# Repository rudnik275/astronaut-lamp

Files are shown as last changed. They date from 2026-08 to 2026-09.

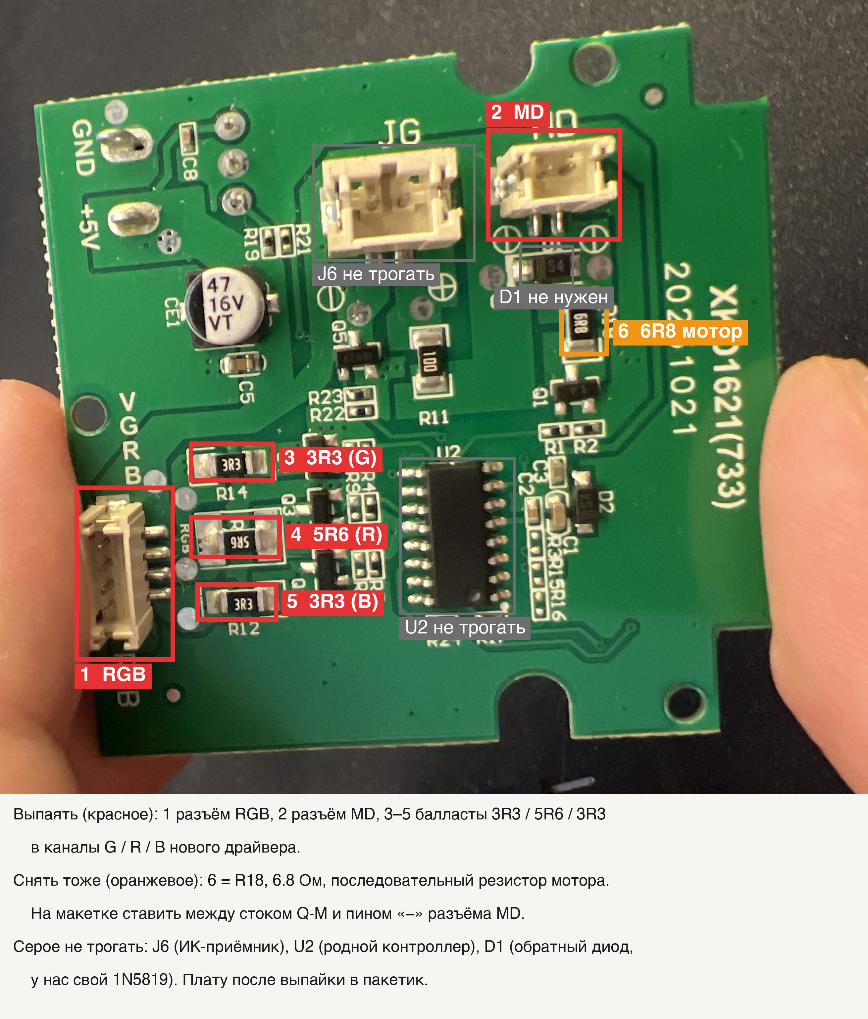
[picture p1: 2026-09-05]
photos/board-XKD1621-desolder.jpg

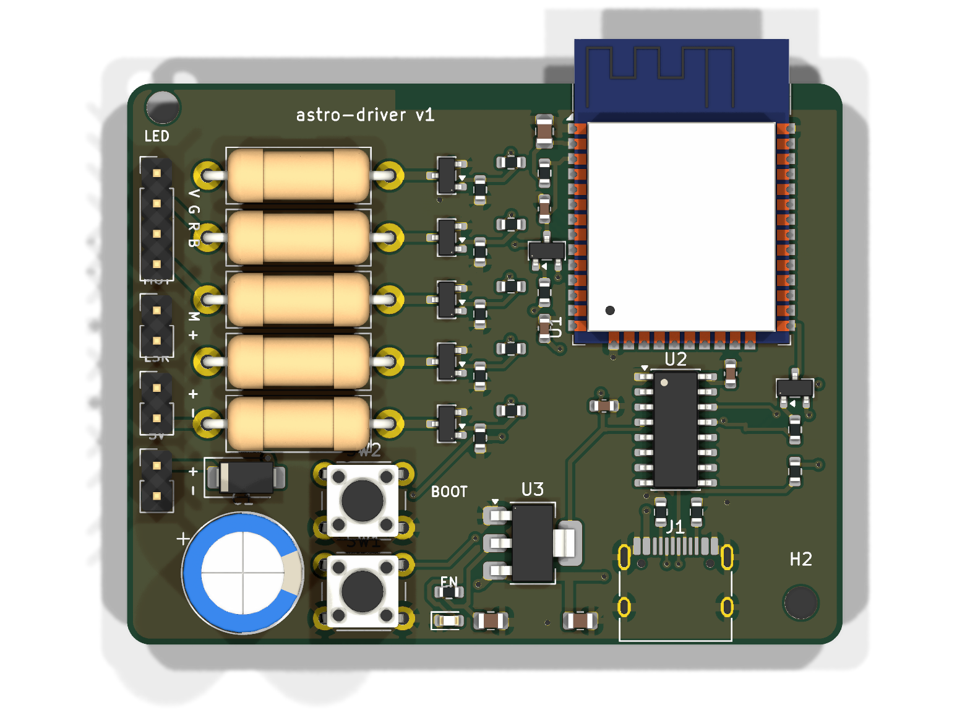
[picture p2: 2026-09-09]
hardware/out/render-top.png

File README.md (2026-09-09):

# Лампа-космонавт → нативное устройство Apple HomeKit

Ночник «космонавт на луне» + звёздный проектор (Rozetka 566431028, AURA_HUB, ~530 грн).
Куплен и разобран 2026-08-23. **Решение: выкидываем ИК-пульт и родной контроллер,
внутрь ставим ESP32-WROOM-32 с прошивкой HAA — лампа появляется в Apple Home как
настоящая цветная LED-лампа + отдельный выключатель проектора, без хабов и мостов.**

## Статус на 2026-09-05 (точка входа для новой сессии)

- ✅ **ESP32 прошит HAA 12.18.1 (04.09)** и **спарен с Home.app**. Чип ESP32-D0WD-V3,
  порт `/dev/cu.usbserial-120`, точка доступа setup-режима `HAA-620DA0`, код спаривания
  `0218-2017`. Имена в Home.app: аксессуар «Космонавт», лампа «Цвет неба», мотор
  «Движение неба». Уровни на GPIO проверены мультиметром: 25 = R, 26 = G, 27 = B, 32 = мотор
- ✅ **С донора выпаяны и промерены** балласты `5R6` (R) и 2× `3R3` (G, B) **плюс `6R8` (R18)**
  из цепи мотора — на доноре мотор шёл `MD → D1 → 6R8 → Q1`, а не напрямую (§1, §3).
  Гнёзда `RGB`/`MD` оказались SMD с шагом 2.0 мм: вилки с кабелей срезаны, кабели теперь
  с голыми концами, провода светодиода опознать по фото вилок
- 📐 **Схема, таблица соединений для breadboard, порядок работ и раскладка в корпус:**
  `docs/schematic.html` (та же страница опубликована как артефакт, ссылка в памяти сессии).
  Конфиг HAA, залитый в плату: `docs/haa-config.json`. Размеченное фото донора:
  `photos/board-XKD1621-desolder.jpg`
- 🔧 **Монтаж на перфборде (08.09):** `docs/wiring.html` — карта 14 проводов (пин ESP32 →
  отверстие), раскладка по отверстиям платы 10 × 24 (вид сверху и зеркальный вид снизу),
  правила пайки на перфборде, порядок сборки, чеклист. Раскладка: TO-220 плашмя, ноги в ряд H,
  резисторы стоя в рядах I–J, шина GND голым проводом по ряду G снизу, шина +5 по ряду I
  в колонках 21–24, C1 на боку в колонках 21–24, D1 в `I20–I21`. 10 кОм стоит со стороны GPIO
  от 220 Ом (эквивалентно схеме). Плата берётся целиком, 25.4 × 61 мм после обрезки полей —
  отсек ранца считать под неё, а не под 24 × 58. Связи раскладки проверяются скриптом на
  самой странице (18 цепей, замыканий и разрывов нет)
- 🖨️ **Печатная плата astro-driver v1 (09.09):** `hardware/` — проект KiCad 10 с ESP32-WROOM-32E
  на плате, USB-C (питание + прошивка через CH340C), пять ключей AO3400A (R, G, B, мотор,
  лазер на GPIO 33), выводные балласты 2 Вт и 1000 µF под ручную пайку. 60 × 47 мм.
  Схема и плата генерируются из `hardware/design.py` (`sh hardware/run.sh all`), нетлист
  схемы сверен с платой, DRC без электрических ошибок, 0 неразведённых. Гербер, BOM/CPL
  для сборки на JLCPCB, рендер и PDF схемы в `hardware/out/`. Цена: голые платы ~15–22 $
  за 5 шт, со сборкой SMD ~40–50 $ за 2 шт / ~55–70 $ за 5 шт (оценка, `hardware/README.md`).
  **На железе не проверено**, первая партия — прототип. Лазер в текущей ручной сборке
  висит параллельно мотору; на плате у него свой канал
- 🧩 **Корпус: печатаем новый ранец.** Отсек 63 × 52 × 20 мм, ESP32 со срезанной гребёнкой
  плашмя + полоска перфборда 24 × 58 рядом, один слой (раскладка в `docs/schematic.html`).
  Вход питания — **USB-C** вместо круглого: в корзине Али два кандидата с 5.1 кОм — на фланце
  (item 1005006939718172) и платка без фланца Choice (item 1005012148102188); 2-pin без CC
  и XH2.54 не брать (§4)
- ✅ **Драйвер спаян и работает (08.09):** перфборд по схеме §3 (своя раскладка), лампа
  и мотор управляются из Home.app. Лазер звёзд (разъём `JG` донора, §1) в параллель мотору
  через `R11` 10 Ом. **Решение 09.09: железо закрыто в таком виде**, пятый ключ, пересборка
  и печатная плата не делаются
- ⏭️ **Следующий и последний шаг:** конфиг HAA с эффектами (`"fx"`, плитки-выключатели
  эффектов), залить по Wi-Fi через режим настройки — [issue #3](https://github.com/rudnik275/astronaut-lamp/issues/3)
- 📄 Инвентарь деталей: Obsidian `справочники/электроника-инвентарь.md`; где покупать —
  `справочники/электроника-где-покупать.md` (там же USB-C гнёзда по трём магазинам)
- 🧭 Дальше по плану работ — §6

Связанные проекты: [nodemcu-co2](../nodemcu-co2/) (общий пул плат), Fusion/3D-печать
(держатель платы внутри основания — печатает друг, Bambu A1, PETG).

---

## 1. Что внутри (по фото разобранного основания)

Родная плата: **`XKD1621(733)`**, дата-код `231021`. Питание 5 В (пады `+5V` / `GND`
внизу справа), электролит 47 µF 16 V.

| Разъём / метка | Пины | Что это |
|---|---|---|
| `RGB` | 4: `V G R B` | **Аналоговый RGB-светодиод, общий анод** (`V` = +5 В). Ключи `Q2/Q3/Q4` (SOT-23) стоят по низкой стороне на R/G/B, рядом балласты `3R3`. |
| `MD` | 2 | Мотор звёздного проектора (`MD` = motor drive). Цепь по чистому фото (05.09): `MD → D1` (Шоттки `S4`) `→ R18 = 6R8 → Q1`. **Не Q5**, как думали по первому фото: `Q5` с `R11` (10 Ом) стоит у `J6`. |
| `JG` | 2 | **Лазер звёзд** (`JG` = 激光 jīguāng, лазер; раньше по фото ошибочно считали ИК-приёмником `J6`). Его драйвер: ключ `Q5` (SOT-23) + `R11` = `100` (10 Ом) последовательно + электролит `CE1` 47 µF. Уточнено 08.09.2026, когда после сборки не оказалось звёзд. Лазер полярный, в отличие от мотора. |
| `U2` | SOIC-16 | Родной контроллер: декодирует пульт, гонит ШИМ на Q2–Q4. Его и выбрасываем. |

**Ключевой вывод:** здесь **НЕ адресная лента (не WS2812B)**, а обычный RGB с общим
анодом на трёх ШИМ-каналах. Значит не нужны ни level shifter 3.3→5 В, ни DMA-пины,
ни ограничения WLED по GPIO. Задача сводится к «три ШИМ-канала + один ключ мотора».

Сам номер платы `XKD1621(733)` — это внутренний код китайского ODM-цеха, даташита нет
нигде и не будет (искали EN+ZH — ноль). Опознаём снизу вверх по функциям, и это не
проблема: схема этого класса ламп стандартна и совпала с референс-дизайнами
(Cmsemicon SC8F052 и подобные) пин-в-пин — «RGB-выходы active-low, общий анод, три
NPN/ключа по низкой стороне, 3-проводной ИК-приёмник». То есть наши догадки по фото
подтверждаются типовым дизайном.

### Что переиспользуем с платы, а что выкидываем

Ключевая мысль: **RGB-светодиод и мотор сидят на съёмных разъёмах** (белые JST на фото).
Их можно просто **отстегнуть от родной платы и воткнуть в свой драйвер на ноде** —
резать провода не обязательно.

| С платы | Решение |
|---|---|
| **RGB-светодиод** (разъём `RGB`, `V G R B`) | **Переиспользуем.** Это и есть свет лампы. `V` = общий +5 В анод. |
| **Мотор проектора** (разъём `MD`) | **Переиспользуем.** Отдельный ключ = отдельный сервис в Home. |
| **Питание 5 В** (родной адаптер → пады `+5V`/`GND`) | **Переиспользуем**, если адаптер тянет (проверить ток, см. §5). |
| Корпус, крепления, JST-разъёмы | **Переиспользуем.** |
| **U2** (16-pin) — родной мозг/ИК-декодер | **Выкидываем**, его роль берёт NodeMCU. |
| **J6** (3 пина) — ИК-приёмник | **Не нужен**, управление по Wi-Fi. |
| Q2/Q3/Q4 (ключи RGB), Q5 (ключ мотора) | **Опционально** — см. две стратегии ниже. |

**Стратегия A — свой драйвер (выбрана и реализована).** Родную плату не трогаем
вообще: отстёгиваем разъёмы `RGB` и `MD`, ведём их в свой маленький драйвер на 4
logic-level MOSFET (схема в §3). *Поправка 04.09: гнёзда на плате оказались SMD с шагом
2.0 мм, dupont в вилки не входит, поэтому вилки с кабелей срезаны и кабели идут в драйвер
голыми концами. С платы сняты только четыре резистора: `5R6`, 2× `3R3`, `6R8`.* Плюс: полностью известная схема, никакой пайки SOIC.
Минус: докупить 4 транзистора (копейки).

**Стратегия B — переиспользовать родные ключи (экономит детали).** Выпаять U2 и
подать ШИМ с ноды прямо на входы Q2/Q3/Q4/Q5 (через их же базовые/затворные резисторы).
Плюс: 0 новых деталей. Минусы: надо выпаять 16-ногую SOIC (лучше феном) и прозвонить,
какая нога куда шла; работает чисто, **если** ключи — это NPN-биполярники (для 5-В лампы
очень вероятно, референс использует S8050) или logic-level MOSFET. Если это MOSFET с
высоким порогом — от 3.3 В не откроются, тогда всё равно Стратегия A.

**Как выбрать за 2 минуты мультиметром:** посмотреть на вход Q2. Резистор ~1 кОм в
управляющую ногу = биполярник (Стратегия B безопасна). Голый затвор + подтяжка вниз =
MOSFET (проверить порог). Не хочешь возиться — бери Стратегию A.

**Стратегия C — ИК-инъекция (идея Димы): плату не трогаем вообще, выбрасываем ИК-приёмник
и подаём сигнал с ESP прямо на его пин.** Разобрана отдельно в §2.5. Электрически чисто и
это самый быстрый путь, но платой управляет по-прежнему родной U2, а он понимает только
язык пульта — поэтому в Home.app получится не лампа, а набор кнопок. Подробности и
цифры — там же.

### Сравнение трёх стратегий

| | Что делаем | Цвет в Home.app | Яркость | Состояние | Цена |
|---|---|---|---|---|---|
| **A. Свой драйвер** | 4 MOSFET на макетке, ESP рулит светодиодом напрямую | **любой, цветовой круг** | **плавно 0–100 %** | **точное** | 4 транзистора + час пайки |
| **B. Убить U2** | выпаять SOIC-16, ШИМ с ESP на базы родных ключей | **любой, цветовой круг** | **плавно 0–100 %** | **точное** | фен + прозвонка, 0 покупок |
| **C. ИК-инъекция** | один провод в разъём `J6`, ESP притворяется пультом | только **16 пресетов** | только ступеньками `±` | **вслепую** | один провод |

**Рекомендация: A** (или B, если любишь паять и не хочешь ничего покупать). Стратегия C
даёт «умную лампу» в кавычках — ровно то, от чего отказались в самом начале, просто
без ИК-светодиода.

---

## 2. Архитектура (выбрана)

**NodeMCU V3 (ESP8266) + прошивка HAA (Home Accessory Architect, RavenSystem).**

HAA — единственная живая прошивка с **нативным HomeKit на ESP8266** (последний релиз
v12.18.1 «Merlin», 2026-07-26). Лампа регистрируется в Home.app **как настоящий
HomeKit-аксессуар: без Home Assistant, без Homebridge, без NAS и без моста**.
Поддерживает ровно нашу схему: Lightbulb с ШИМ-каналами `"g":[R,G,B]`, плюс вторым
сервисом Switch на мотор проектора.

⚠️ **Бинарники лежат в репозитории `RavenSystem/haa`, а не в `esp-homekit-devices`** —
у второго в релизах вообще нет файлов, только changelog. Проверено 2026-08-23: в релизе
12.18.1 лежит 80 ассетов, ESP8266-сборки — это файлы **без суффикса** `_esp32*`
(`fullhaaboot.bin`, `haamain.bin`, `otamain.bin`). Сборки живые, не остатки: размер
`haamain.bin` меняется от релиза к релизу, и заголовок `fullhaaboot.bin` — настоящий
ESP8266-образ (magic `0xE9`, точка входа `0x401008dc` в IRAM ESP8266).

- Релизы (бинарники): https://github.com/RavenSystem/haa/releases
- Wiki Lightbulb: https://github.com/RavenSystem/esp-homekit-devices/wiki/Lightbulb
- Wiki GPIO: https://github.com/RavenSystem/esp-homekit-devices/wiki/GPIOs-Configuration
- Wiki установки: https://github.com/RavenSystem/esp-homekit-devices/wiki/Installation

### Честно про риски ESP8266 (перепроверка 2026-08-23)

Плана это не ломает, но знать надо:

- **ESP8266 у HAA в режиме «поддерживаем, но не развиваем».** Все новые фичи идут только
  под ESP32 (HTTPS, MQTT, хардварный ШИМ, ADC-режимы). Автор прямым текстом в issue #2407:
  Wi-Fi-драйвер закрытый, а **SDK под ESP8266 Espressif забросил** (последний
  ESP8266_RTOS_SDK v3.4 — апрель 2021), поэтому баги Wi-Fi-слоя он починить не может.
- **Сам чип ESP8266EX — NRND с ноября 2025** (не рекомендован для новых разработок).
- Был реальный регресс в 2026: на 12.16 часть ESP8266-устройств отваливалась (issue #2408),
  закрыт как невоспроизводимый после 12.17.
- **Вывод:** для этой лампы ESP8266 берём осознанно — плата уже есть, задача простая
  (3 ШИМ + бинарный выход). Если бы железо покупалось с нуля — брал бы ESP32-C6.

### Прошивка HAA: конкретика

> ⚠️ **Секция историческая — писалась под ESP8266, до смены платы.** Номера GPIO
> (5/4/14/12), режим ШИМ `7` и команды esptool с `-fs 1MB -fm dout` здесь НЕ для
> нашего ESP32. Актуальное: пины и конфиг — §3, команды прошивки ESP32 — §6.
> Общие вещи (массив `"io"` обязателен, `"es"`-группировка, initial value) верны для обеих плат.

**Мотор делаем БИНАРНЫМ выходом, а не ШИМ.** Это важно: софтверный ШИМ на ESP8266
ограничен **2000 Гц** (дефолт 305 Гц), и мотор на такой частоте будет слышимо пищать.
Нам скорость вращения регулировать не надо — только вкл/выкл, поэтому проблемы нет.
Если позже захочется «медленное вращение» — это аргумент за ESP32 (там хардварный ШИМ
до 29 кГц), на ESP8266 будет писк.

**Лимит, который надо помнить:** одна служба Lightbulb принимает **максимум 5 ШИМ-каналов**
(в исходниках `uint8_t gpio[5]`). Наши R/G/B — три, всё ок, но мотор четвёртым каналом
лампы сделать нельзя даже при желании — только отдельным сервисом. Мы так и планировали.

**ШИМ НЕ инвертируем.** Общий анод + N-ключ по низкой стороне = «единица на затворе»
означает «горит», это нормальный режим (`PWM mode 0` — дефолт). Но **осознанно задать
initial value**, иначе на старте лампа может вспыхнуть на полную до инициализации службы.

Скелет конфига (R/G/B на GPIO 5/4/14, мотор на GPIO 12). Обязателен массив `"io"` —
без него GPIO просто не включатся, это самая частая ошибка новичка:

```json
{
  "c": { "io": [ [[5,4,14], 7], [[12], 2] ] },
  "a": [ {
    "t": 30,
    "g": [5,4,14],
    "es": [ { "t": 1, "0": {"r":[[12,0]]}, "1": {"r":[[12,1]]} } ]
  } ]
}
```

`"c"` — общие настройки, `"a"` — массив аксессуаров, `"es"` — дополнительные службы
внутри аксессуара (так экономится RAM и всё группируется одной плиткой в Home.app).
Режим GPIO `7` = софтверный ШИМ-выход, `2` = бинарный выход. `"t":30` = Lightbulb,
`"t":1` = Switch. Точные ключи сверить по wiki перед заливкой.

**Команды прошивки** (плата 4 МБ, но образ собран под 1 МБ — флаг `-fs 1MB` правильный,
«помогать» флагом `4MB` не надо; GPIO0 на GND для входа в режим прошивки):

```
python3 -m esptool flash_id
python3 -m esptool erase_flash
python3 -m esptool -b 115200 --before=default_reset --after=hard_reset write_flash -fs 1MB -fm dout 0x0 fullhaaboot.bin
```

В Home.app будет предупреждение «непроверенный аксессуар» → **«Всё равно добавить»**.

В Home.app получится **один аксессуар с двумя сервисами**: «Космонавт» (цвет + яркость)
и «Звёздное небо» (вкл/выкл, при желании — скорость вращения через ШИМ).

### Почему не альтернативы

| Путь | Вердикт |
|---|---|
| **HAA (выбран)** | Нативный HAP, нулевая инфраструктура, PWM RGB из коробки. Минус: конфиг — JSON («MEPLHAA script»), не такой привычный как YAML; спаривание на ESP8266 небыстрое. |
| ESPHome + Home Assistant на NAS + HomeKit Bridge | Полноценный план Б, живее чем казалось: в релизе **ESPHome 2026.1 (январь 2026) поддержку ESP8266 официально переподтвердили** («ESP8266 is no longer a platform we warn users away from»), интеграция в HA — Platinum. Минус прежний: тянет всегда-включённый NAS и мост, нативного HomeKit у ESPHome нет. Плюс: HA крутит свои автоматизации вообще без Apple-хаба. В Docker нужен `network_mode: host` (иначе mDNS не пролезет). |
| WLED | Нативного HomeKit нет вообще, и он про адресные ленты — у нас их нет. Мимо. |
| HomeSpan | Только ESP32. NodeMCU V3 не подходит. |
| Оставить ИК и подменять пульт | Отменено пользователем — хотим настоящее устройство, а не эмуляцию кнопок. |
| **Aqara Hub M3** (встроенный ИК-бластер) | Не отменяет план — см. ниже. Даёт ту же «эмуляцию кнопок», от которой отказались, и лампой-с-цветовым-кругом она в Home.app не станет. |

### Про Aqara Hub (и любой хаб): ноду он в HomeKit НЕ заведёт — и не нужен

Путь «NodeMCU → Apple HomeKit **через Aqara Hub**» не работает, причём по двум
независимым причинам сразу (перепроверено 2026-08-23):

1. **Со стороны ноды.** У ESP8266 нет ни Zigbee, ни Thread (802.15.4-радио в нём
   физически отсутствует — даташит ESP8266EX), ни Matter. Причём Matter — это не
   «пока не портировали»: порта `ESP8266` в `connectedhomeip` не существовало никогда,
   и все три стека живут в ESP-IDF, для которого ESP8266 вообще не является таргетом.
2. **Со стороны хаба — и это добивает.** Aqara-хаб бриджит **только устройства самой
   Aqara**. Даже чужой *Zigbee*-девайс он не примет: официальный ответ поддержки Aqara
   (форум, 2025) — «the hub currently supports only Aqara Zigbee devices and not
   third-party Zigbee ones», у них это даже в названиях товаров на Amazon написано
   («Features Aqara Zigbee (Not Third-Party)»). Третьесторонние устройства у M3/M100/M200
   принимаются **только по Matter**.

То есть даже гипотетический «привинтить к ноде Zigbee-модуль» не спас бы. Звена
«нода → Aqara → HomeKit» не существует ни в каком виде.

**И хаб для этого не нужен.** Прошивка **HAA** делает саму ноду **нативным
HomeKit-аксессуаром прямо по Wi-Fi** — лампа появляется в Home.app напрямую, без всякого
моста. Это меньше звеньев и надёжнее любого хаба: локальное управление с айфона.
HomePod/Apple TV — как и для любого HomeKit-устройства — нужен только для автоматизаций
по расписанию и доступа извне, но не для того, чтобы лампа работала дома.

Если хочется задействовать уже купленный Aqara-хаб — **эту лампу он не потянет**, это
мост не того типа. Хаб пусть остаётся под датчики Aqara / Zigbee / кондиционер.

> Если бы стояла ESP32 (а не ESP8266), появился бы Matter — но и тогда устройство
> правильнее сдавать **напрямую** в Apple Home, а не гонять через Aqara. На нашей ноде
> вопрос закрыт: HAA, напрямую по Wi-Fi.

⚠️ HomeKit-аксессуар спаривается **только с одним контроллером**: либо Apple Home,
либо Home Assistant. Выбираем Apple Home.

⚠️ **Хаб**: управление с iPhone в той же Wi-Fi работает без хаба. Для автоматизаций
(«включить на закате»), Siri вне дома и удалённого доступа нужен HomePod / Apple TV.
Поддержка iPad как хаба закончилась 2026-02-10.

⚠️ ESP8266 — **только 2.4 ГГц Wi-Fi**. На роутере должен быть доступен 2.4-ГГц SSID.

---

## 2.5 Стратегия C: ИК-инъекция в пин приёмника — разбор

**Идея:** родную плату не переделываем совсем. Выбрасываем ИК-приёмник, а на его
сигнальный пин (разъём `J6`) подаём с ESP тот же цифровой сигнал, который выдавал бы
приёмник, — U2 думает, что нажали кнопку на пульте. Идея рабочая, приём известный,
и разъём `J6` делает её обратимой без единого разреза: приёмник просто **отстёгивается**.

### Электрическая часть — тут всё сходится

Выход ИК-приёмника (VS1838B / TSOP-класс) — **открытый коллектор с внутренней подтяжкой
~30 кОм**, покой = **HIGH**, приём пачки = **LOW** (подтверждено даташитами Vishay и Sivago).
Значит с ESP надо выдавать **инвертированную огибающую без несущей**: покой HIGH,
9000 мкс LOW, 4500 мкс HIGH, дальше биты 560 мкс LOW + (560 = «0» / 1690 = «1»), 32 бита,
хвост 560 мкс LOW. Это протокол NEC, 38 кГц — у этих ламп он практически всегда.

Два важных следствия:

- **Пин ESP настраивать как open-drain, а не push-pull.** Тогда ESP только «тянет вниз»,
  а HIGH формирует подтяжка от 5 В самой платы → U2 видит честные 5 В, и вопрос
  «прочитает ли 5-вольтовый вход наши 3.3 В» **снимается полностью**. Иначе он вполне
  реален: для 5-В CMOS порог V_IH = 3.5 В, а у нас 3.3 В — не проходит.
- ⚠️ **Раз приёмник выбрасываем — вместе с ним уходит его подтяжка 30 кОм.** На дешёвых
  платах своей часто нет. **Померить линию `J6` после снятия приёмника**: если висит в
  воздухе — впаять 4.7–10 кОм на +5 В, иначе U2 будет ловить мусор.

Прецеденты есть, приём описан: ctuck (10-Вт RGB-прожектор, 44-кнопочный пульт),
Wolfgang Ziegler, тред на All About Circuits, ESPHome-проект Daikin.

### HAA это умеет, но через недокументированную дверь

HAA шлёт ИК действием `"i"` внутри аксессуара. Проблема: по умолчанию он выдаёт
**модулированную несущую 38 кГц** — для ИК-светодиода. Нам нужна **несущая выключенной**,
иначе U2 увидит не чистый LOW, а дребезг.

Разбор исходников v12.18.1 (`irrf_tx_task()`): при `freq <= 1` HAA переключается на
«RF-путь» и выдаёт **ровный уровень без несущей** — ровно то, что надо. Но:

- включается это **только глобально**, через `"x": 500` (внутри считается `1000/500/2 = 1`).
  `"x": 0` **нельзя** — деление на ноль;
- пин и инверсия задаются **недокументированными ключами** `"g"` (GPIO) и `"k"` (инверсия),
  в wiki их нет вообще;
- разбор `"x"` срабатывает, только если объявлен ещё и `"t"` — нужен **фиктивный** `"t"`
  на неиспользуемый пин, иначе молча вернётся 38 кГц;
- задать несущую по-действию (`"x":1` внутри `"i"`) **не выйдет** — код это значение
  отбрасывает.

⚠️ Всё это выведено **чтением исходников, а не проверено на стенде**. Запасной вариант,
полностью документированный, — не выбрасывать приёмник, а приклеить напротив него
ИК-светодиод и светить в упор. Но раз приёмник выбрасываем, этот запасной путь закрыт.

**Коды надо снять со своего пульта.** У WLED в базе шесть разных вариантов
24-кнопочных пультов — клоны отличаются, чужим таблицам верить нельзя. В HAA есть
захват (только в Setup Mode), причём **можно ловить прямо с линии родного приёмника**,
пока он ещё на месте, — отдельная железка не нужна. Снять коды надо **до** того, как
приёмник выброшен.

### Чем за это платим — главное

Управлять лампой продолжает **родной U2**, а он понимает только язык пульта:

- **Цвет — только фиксированная палитра**, 16 кнопок у 24-клавишного пульта (20 у
  44-клавишного). Произвольного RGB нет: команды «выставь #A3F0C1» в пульте не существует.
- **Яркость — только относительная**, кнопками `+`/`-` (~16 ступеней). **Абсолютной команды
  нет ни в одном наборе кодов.** HomeKit присылает «поставь 42 %», а мы можем только
  «нажать минус N раз» вслепую. Хуже: в динамических режимах те же кнопки превращаются
  в регулятор скорости — перед яркостью надо всегда сначала слать статичный цвет.
- **Обратной связи нет вообще.** Состояние держим в уме; после моргания питания U2
  сбрасывается в своё, а плитка в Home.app продолжает врать.
- **И самое неприятное для HomeKit:** у HAA wildcard-действия для Lightbulb есть **только
  по яркости** (`"y0"`), **по оттенку — нет**. То есть цветовой круг Home.app к палитре из
  16 кнопок привязать нечем. Придётся делать либо N отдельных выключателей, либо
  сервис TV со списком «входов» как палитрой.
- Хорошая новость по кнопке питания: у 24-клавишных пультов **ON и OFF — раздельные
  команды**, значит выключение идемпотентно и состояние хотя бы не уплывает по питанию.
  У 44-клавишных питание — один тумблер, и вот там состояние поплывёт неизбежно.
- Мотор проектора управляется только если под него есть кнопка на пульте — иначе к нему
  всё равно тянуть провод.

**Итог: в Home.app получится не лампа, а пульт в виде плиток.** Разница с вариантом A —
четыре транзистора и час пайки.

## 3. Схема

### ⚠️ Плата: берём ESP32-WROOM-32 DevKit, а не NodeMCU V3

Решение изменено 2026-08-23 после проверки. Причина одна и она по существу задачи:
**у ESP8266 вообще нет аппаратного ШИМ.** HAA на нём умеет только программный ШИМ с
потолком 2000 Гц (по умолчанию 305 Гц), который крутит сам процессор — а мы просим
три канала одновременно, пока рядом работают Wi-Fi и HomeKit. Это прямой риск мерцания
и дёрганой яркости, то есть ровно той функции, ради которой всё делается.

У ESP32 это аппаратный блок **LEDC**: 8 каналов, 4 таймера, **1 Гц – 29 кГц**
(в HAA — режим GPIO `9`, дефолт 5 кГц). Яркость держится железом и firmware-нагрузке
безразлична. Бонусом NodeMCU V3 остаётся свободной под CO2-монитор, как и планировалось.

**ESP32-C3 SuperMini (тот, что 150 грн) — не брать.** У него два подтверждённых дефекта:
керамическая антенна CA-C03 поставлена без зазора и платы просто не подключаются к
Wi-Fi на полной мощности передатчика (замеры sigmdel на 4 платах: 1250 мс против 50 мс
после снижения TX power), плюс на части партий стоит LDO на 250 мА при пиках чипа до
335 мА. В пластиковом основании рядом с коллекторным моторчиком это лишняя лотерея.

### Схема

```
   5 В от родного адаптера
        │
        ├──► ESP32 DevKit, пин VIN/5V   (GND — общий со всем)
        │
        ├──► пин V разъёма RGB          (общий анод светодиода)
        │
        └──► + мотора проектора
                                         ESP32-WROOM-32
   RGB.R ──[5R6]──► сток Q_R ──┐         GPIO25 ──[220 Ω]──► затвор Q_R
   RGB.G ──[3R3]──► сток Q_G ──┼─ исток  GPIO26 ──[220 Ω]──► затвор Q_G
   RGB.B ──[3R3]──► сток Q_B ──┤  на GND GPIO27 ──[220 Ω]──► затвор Q_B
   мотор ──[6R8]──► сток Q_M ──┘         GPIO32 ──[220 Ω]──► затвор Q_M

   [5R6]/[3R3] — балласты каналов, снятые с родной платы XKD1621; привязка к цветам
   подтверждена прозвонкой донора 04.09.2026 (5R6 = R, 3R3 = G и B).
   [6R8] — R18 с той же платы, стоял последовательно с мотором; без него мотор получит
   все 5 В и будет крутиться быстрее задуманного.
   Полная схема с таблицей соединений и пинаутами: docs/schematic.html
```

- ⚠️ **БАЛЛАСТНЫЕ РЕЗИСТОРЫ СВЕТОДИОДА — НЕ ЗАБЫТЬ (ревизия 2026-08-24).** Токоограничение
  каналов R/G/B живёт **на родной плате** (SMD `3R3` = 3.3 Ом и `5R6` = 5.6 Ом рядом с
  Q2/Q3/Q4), а не в модуле светодиода. Если воткнуть светодиод в наш драйвер без них —
  ток через кристаллы ничем не ограничен, и ШИМ не спасает (ШИМ режет среднее, а убивает
  пиковый ток). **В каждый канал последовательно нужен балласт**: либо выпаять родные
  `3R3`/`5R6` с платы `XKD1621` и перенести на макетку (бесплатно и номиналы ровно те —
  `5R6` скорее всего красный канал, `3R3` — зелёный/синий), либо купить резисторы
  3.3–5.6 Ом **мощностью 2 Вт** (на ~0.5 А через 3.3 Ом рассеивается ~0.8 Вт, обычный
  0.25 Вт сгорит). Итоговый номинал подобрать после замера тока из §5.
- На каждый затвор: **220 Ω** последовательно + **10 kΩ подтяжка к GND — обязательно**.
  До того как HAA сконфигурирует пины (сотни мс после старта), все GPIO висят в воздухе,
  и без подтяжки состояние лампы и мотора при каждой загрузке непредсказуемо.
  (100 Ω было бы каноничнее, но во Всеплюсе его нет, а 220 Ω для наших частот — то же самое.)
- Через мотор — **обратный диод 1N5819** катодом к +5 В, иначе выброс убьёт ключ.
- По питанию 5 В — **1000 µF** электролит рядом с платой.
- ШИМ **не инвертированный**: общий анод + N-ключ по низкой стороне, «затвор в 1» = горит.

**Выбор GPIO не случайный.** У ESP32 нельзя трогать: `0, 2, 5, 12, 15` (strapping —
плата не загрузится или выберет не то напряжение флеша), `6–11` (флеш), `1, 3` (UART0,
на них сыплется лог загрузки), `34–39` (только вход). Пины `25/26/27/32` чистые.

Конфиг HAA под эту схему — аппаратный ШИМ, мотор простым выходом:
`"io":[[[25,26,27],9,0,0,0,0],[[32],2,0,0]]` (точную сигнатуру `io`-массива сверить по
wiki перед заливкой). `"y":[1000]` можно вообще опустить — дефолт аппаратного ШИМ 5 кГц,
он только глаже.

**Опция после смены платы (ревизия 2026-08-24): мотору можно дать СКОРОСТЬ.** Правило
«мотор — только бинарный выход» пришло из эпохи ESP8266 (софт-ШИМ ≤2 кГц = слышимый писк)
и на ESP32 устарело: аппаратный LEDC тянет 20+ кГц — выше слышимого диапазона, мотор
не пищит. То есть GPIO32 можно сделать ШИМ-каналом и отдать «Звёздное небо» в Home.app
Fan-сервисом с регулировкой скорости вращения (код типа сервиса — по wiki). Бинарный
вкл/выкл проще и остаётся дефолтом; скорость — бесплатный апгрейд, если захочется
«медленное небо». Железо одно и то же, меняется только конфиг.

**MOSFET-ы обязательно logic-level** (открываются от 3.3 В): `IRLZ44N` (TO-220, удобно
паять руками, с большим запасом) или `AO3400A` (SOT-23). ❌ **Не брать `IRF540`** и
готовые модули на нём — порог затвора до 4 В, от 3.3 В он толком не откроется.

---

## 4. Что купить — корзина Всеплюс (проверено 2026-08-23)

**Магазин: `vseplus.com`.** Проверялись оба, РКС отпадает: там нет в наличии ни NodeMCU,
ни ESP32 DevKit (только WeMos D1 mini и ESP32-C6 в количестве 2 шт), а JST на 3 и 4 пина
идут с минималкой 500–1000 шт под заказ. Всеплюс закрывает весь список одним заказом.
Цены — «специальная» (по лояльности) там, где магазин показывает две.

| Позиция | Зачем | Кол-во | Грн | Ссылка |
|---|---|---|---|---|
✅ **Корзина собрана на сайте 2026-08-23, фактическая сумма — 656 грн.** Расхождение с
расчётными 530 объясняется двумя вещами, обе выяснились только при оформлении:
**у магазина есть минимальные партии** (диоды — от 10 шт, макетка — от 2 шт) и
**«спец. ціна» не действует на первый заказ** — она даётся после двух оплаченных,
а я считал по ней. Ниже колонка «Грн» — фактическая, за всю позицию.

| Позиция | Зачем | Кол-во | Грн | Ссылка |
|---|---|---|---|---|
| Плата розробника **ESP32-WROOM-32** | мозг | 1 | **265** | [ссылка](https://vseplus.com/ua/product/plata-rozrobnika-esp32-wroom-32-553955) |
| Транзистор **IRLZ44NPBF** (TO-220) | 3 канала цвета + мотор | 4 | **248** | [ссылка](https://vseplus.com/ua/product/tranzistor-polovij-n-kanalnij-irlz44npbf-128604) |
| ~~Резистор 220 Ом~~ | ✅ **есть, 20 шт** (`CF1/4W-220R`) | — | — | — |
| ~~Резистор 10 кОм~~ | ✅ **есть, 10 шт** (`MFR100SSFTB-10KR`, 1 Вт — крупные, но рабочие) | — | — | — |
| Діод **1N5819** | обратный на мотор | **10** (мин. партия) | **40** | [ссылка](https://vseplus.com/ua/product/diod-1n5819-127851) — Шоттки, DO-41, 40 В, 1 А |
| Конденсатор **1000 мкФ 16 В** | по питанию | 1 | **17** | [ссылка](https://vseplus.com/ua/product/kondensator-elektroliticnij-vividnij-90291) — номинал проверен: 1000 uF / 16 V / 105 °C |
| **Макетна плата 3×7** двостороння | на неё паяем драйвер | **2** (мин. партия) | **86** | [ссылка](https://vseplus.com/ua/product/maketna-plata-3x7-dvostoronna-zelena-122222) — 30×70 мм |
| ~~Макетна плата 400 контактів~~ | ✅ **уже есть у Димы** | — | — | — |
| ~~Dupont тато-мама / тато-тато~~ | ✅ **есть, по ~40 шт каждого** | — | — | — |
| ~~Провід монтажний 24AWG~~ | ✅ **есть** (катушка почти пустая, добить по остатку) | — | — | — |
| ~~Обплетення Pro'sKit 8PK-031A~~ | ✅ **есть** (не попала на фото) | — | — | — |
| | | **Итого** | **656 грн** | |

📦 **Заказ получен 03.09.2026** (накладная № 49044674 от 27.08.2026). Позиции
пересчитаны по накладной и сошлись с таблицей выше. Той же поставкой пришла вторая
накладная на 354 грн — крепёж, 100× резистор 330 Ом 0.25 Вт и электролит 470 мкФ 35 В;
к этому проекту она не относится, но лежит в общем пуле (см. инвентарь).

📦 **Инвентарь того, что уже есть, ведётся в Obsidian:**
`справочники/электроника-инвентарь.md` (составлен 2026-08-23 по фото). Сверяться перед
любой закупкой. Вычеркнутые строки выше — оттуда.

### Плата: решено брать ESP32 сразу (Дима, 2026-08-23)

Вариант «собрать на своей NodeMCU и посмотреть, мерцает ли» **отклонён** — берём ESP32
без промежуточного шага. Обоснование то же, что в §3: аппаратный ШИМ (LEDC) снимает риск
мерцания конструктивно, а не «на глаз», и не придётся потом перепаивать.

Обе NodeMCU (их у Димы две — разные USB-чипы `CH340` и `CP2102`) остаются свободными:
одна под [[птичка-co2]], вторая в запас.

**Чего в закромах не нашлось совсем:** ни одного MOSFET, ни конденсаторов, ни диодов
россыпью, ни перфборда, ни оплётки. Симисторы `BT136-600E` и твердотельные реле
`G3MB-202P`, которые есть, **для этой задачи не годятся** — они про коммутацию 220 В
переменного тока, а нам нужен низковольтный DC и плавный ШИМ.

**Опционально:**

| Позиция | Когда нужно | Грн | Ссылка |
|---|---|---|---|
| Набір роз'ємів **XH2.54** | если родные JST не переживут выпайку | 165 | `/ua/product/nabir-rozemiv-xh254-90103` |
| ~~БЖ 5V 2A~~ | ✅ **не нужен — у Димы есть USB 5 В 2 А** | — | — |
| Відсмоктувач припою **ZD-808** | если оплётки мало | 216 | `/ua/product/vidsmoktuvac-pripou-zd-808-209446` |

### Сравнение с РКС: дробить заказ не стоит (кроме одного случая)

Считано 2026-08-23 **с НДС** — это принципиально: у РКС на сайте **по умолчанию включён
режим «Ціна без ПДВ»**, и их ценники выглядят на 20 % привлекательнее, чем есть на самом
деле. Всеплюс показывает финальную цену. Плюс у РКС на мелочёвке минималки: резисторы —
от 30 шт, диоды — от 10, конденсаторы — от 5.

| Позиция | Всеплюс | РКС (с ПДВ) | Кто дешевле |
|---|---|---|---|
| Плата ESP32-WROOM-32 | **265** | нет в наличии | **только Всеплюс** |
| IRLZ44N ×4 | **208** | 216 | Всеплюс (паритет) |
| Резистор 10 кОм | **2** (5 шт) | 25 (мин. 30 шт) | **Всеплюс** |
| Резистор в затворы | **8** (220 Ом, 5 шт) | 25 (100 Ом, мин. 30 шт) | Всеплюс по деньгам, РКС по номиналу |
| 1N5819 ×2 | **6** | 24 (мин. 10 шт) | **Всеплюс** |
| Конденсатор 1000 мкФ | **14** | 24 (мин. 5 шт) | **Всеплюс** |
| Dupont тато-мама | **35** | 90 | **Всеплюс** |
| Dupont тато-тато | **35** | 42 | Всеплюс |
| Провід монтажний | **17** | 26 | Всеплюс |
| Перфборд 3×7 | 35 (1 шт) | **26** (2 шт, мин. 2) | **РКС** — вдвое больше и дешевле |
| Breadboard | 82 (400 конт.) | **67** (BB-801) | **РКС** |
| Оплётка | 94 (Pro'sKit) | **42** (ZD-180 1 мм) | **РКС**, вдвое |
| Відсмоктувач (опц.) | 180 (ZD-809T) | **96** (тот же ZD-809T) | **РКС**, вдвое |

**Вывод: всё берём во Всеплюсе.** Выигрыш от разделения — около **76 грн**, и он целиком
съедается второй доставкой Новой Почтой (~70–90 грн; ни один из магазинов не публикует
порога бесплатной доставки). Плюс у РКС нет наложенного платежа — только предоплата и
обязательная регистрация, тогда как Всеплюс принимает післяплату.

**Единственное исключение — самовывоз.** У РКС есть точка в Киеве:
**РАДІОМАГ, вул. Ушинського, 1** (Пн–Сб 9:00–16:00, закрыто во время тревог).
Всеплюс — только отправка, склад в Ровно, самовывоза нет вообще. Если едешь мимо
Ушинского, имеет смысл разделить так:

- **РКС, самовывозом:** оплётка 42 + отсос 96 + 2 перфборда 26 + breadboard 67 = **231 грн**
  (те же позиции во Всеплюсе — 391 грн, и без отсоса)
- **Всеплюс, доставкой:** плата, транзисторы, резисторы, диоды, конденсатор, dupont,
  провод = **590 грн**

Итого ≈ 820 грн, но с отсосом и лишней макеткой в комплекте, и доставка одна.

**Чего во Всеплюсе нет / что не брать:**

- **Резистор 100 Ом выводной не продаётся** — линейка прыгает с 47 Ом на 200 Ом.
  Берём 220 Ом, для затворов разницы нет.
- **Готовые MOSFET-модули не брать.** Единственный в наличии — на `IRF520`, а он **не**
  logic-level (нужно ~10 В на затвор, от 3.3 В толком не откроется). Модуль на AOD4184
  распродан. Берём дискретные IRLZ44N — они открываются от 3.3 В и по току в разы с запасом.
- **IRLB8721 не брать** — там он стоит 755 грн за штуку, это в 12 раз дороже IRLZ44N.
- **JST-PH 2.0 на 2/3/4 пина** — только кабели и переходники, отдельных разъёмов нет.
  Нам это неважно: родные разъёмы выпаиваем и переставляем.

ИК-светодиод, который планировался под старый путь, **больше не нужен**. Набор гнёзд
XH2.54 тоже: вилки с кабелей срезаны, в корпусе провода пойдут пайкой на перфборд.

### Вход питания — USB-C (решено 2026-09-05)

Раз корпус печатается заново, вместо круглого разъёма ставим гнездо USB-C. Требования:
гнездо на пластинке с двумя отверстиями под винт (окно в стенке + два М2) и **резисторы
5.1 кОм с CC1/CC2 на GND** — без них кабель C → C и любой PD-зарядник не дадут 5 В,
заработает только кабель A → C. В корзине Али (ещё не оплачено): 2 лота × 10 шт «Type-c Waterproof Female
Chassis Connector 16P with PCB Board Dual 5.1K», item `1005006939718172`, 116.51 грн/лот,
резисторы уже внутри. Запас идёт на [[птичка-co2]] и киндл-дашборд.
Вторая опция в той же корзине (05.09): платка без фланца «Type C Female … Dual 5.1K … 5/6Pin»,
item `1005012148102188`, 10 шт за 122.50 грн, Choice (доставка бесплатно). Электрически то же
самое, но держать её должен корпус: паз под платку 15 × 9 мм в стенке, окно под нос гнезда,
задний упор и прижим крышкой. Какой из двух типов ставить — решить, когда оба приедут. Украинские варианты
(РКС CR-24 5-pin, Всеплюс модуль 717836 + 5.1 кОм) — в `электроника-где-покупать.md`.
Потолок такого входа — 5 В × 3 А = 15 Вт; для ленты на 2 м нужен PD-триггер, не это гнездо.

---

## 5. Что замерить/уточнить перед сборкой

### ✅ ПРОВЕРЕНО 2026-08-23: ОБЩИЙ АНОД. Вопрос закрыт, корзина в силе

Тест A пройден: на обесточенной плате прозвонка между падом `+5V` и пином `V` разъёма
`RGB` **пищит** → `V` сидит на шине +5 В → светодиод с **общим анодом**.

Значит N-канальные ключи по низкой стороне (IRLZ44N) подходят, ШИМ неинвертированный,
состав закупки менять не надо. Ниже — как это проверялось, на случай если понадобится
повторить на другой лампе.

<details>
<summary>Методика проверки (свёрнуто — уже выполнено)</summary>

### Тест A — прозвонка по плате (проще всего, ничего не разбирать)

Идея: если светодиод с общим анодом, то пин `V` разъёма `RGB` на плате физически сидит
на шине **+5 В**. Это просто прозванивается.

1. **Лампу из розетки вынуть.** Питание должно быть отключено.
2. Мультиметр в режим прозвонки `•))`.
3. Один щуп — на пад **`+5V`** внизу платы (там, где припаян плюсовой провод питания),
   второй — на **пин `V`** разъёма `RGB` (крайний, рядом с буквой `V` на шелкографии).
4. Результат:
   - **пищит / около нуля Ом → `V` сидит на +5 В → ОБЩИЙ АНОД, план в силе**;
   - молчит → перепроверить по Тесту B, возможно общий катод.
5. **Контрольная проверка:** тот же пин `V` против пада `GND` — **пищать НЕ должен**.
   Если пищит и там, и там — щупы соскальзывают или где-то замыкание, перемерить.

### Тест B — напрямую на светодиоде (подтверждающий)

Не требует знания шелкографии: ищем общую ногу перебором.

1. Отстегнуть разъём `RGB` от платы, работать с колодкой на шлейфе.
2. Мультиметр в режим диода (позиция `2K`, значок ▷|).
3. **Красный щуп поставить на крайний контакт** и не двигать. Чёрным поочерёдно коснуться
   трёх остальных.
4. Результат:
   - хотя бы на одном появилось число (**красный канал даст ~1.6–2.0 В**) или светодиод
     засветился → **нога под красным щупом = общий анод**;
   - глухо на всех трёх → перенести красный щуп на **противоположный крайний** контакт
     и повторить. Заработало оттуда → это тоже общий анод, просто колодка повёрнута;
   - работает только когда **чёрный** щуп стоит на одной и той же ноге, а красный бегает
     по остальным → **ОБЩИЙ КАТОД**, схему переделывать под P-канальные ключи.

⚠️ **Зелёный и синий каналы могут показывать `1` (OL) — это норма**, у них падение
2.5–3.4 В, а `PM830L` столько не выдаёт (проверено на белом светодиоде 2026-08-23:
светился, но показывал `1`). **Судить по красному каналу.**

Если и Тест B глухой на всех комбинациях — зажечь принудительно: **5 В через резистор
220 Ом**, плюс на предполагаемый `V`, минус на `R`. Загорелось — общий анод.

</details>

### Остальное — можно после заказа
1. ~~**Порядок пинов** на разъёме `RGB`~~ ✅ `V G R B` по шелкографии, прозвонка Димы
   04.09 сошлась; вилки сфотографированы до отрезания — по фото подписать провода.
2. **Ток лампы на белом** — мультиметр в разрыв +5 В **на макетке** (на доноре пришлось бы
   отпаивать питание). Свой USB-блок 5 В 2 А почти наверняка потянет, замер покажет запас.
3. ~~**Что на `J6`**~~ ✅ ИК-приёмник, 3-pin.
4. ~~**Что на `MD`**~~ ✅ мотор, на доноре через `6R8` и `D1` (§1). Ток замерить на макетке.
5. **Есть ли аккумулятор** в корпусе — на плате `XKD1621` зарядки нет; проверить сам
   корпус при разборке под новый ранец.
6. ~~Свободное место~~ ✅ **63 × 52 × 20 мм** в ранце (замер 04.09), ещё немного в голове.
   Раскладка в масштабе — `docs/schematic.html`, раздел «Укладка в ранец».

---

## 6. План работ

- [x] **Проверить общий анод** — ✅ подтверждён прозвонкой 2026-08-23
- [x] Купить компоненты — ✅ **заказ оформлен 2026-08-23**, 656 грн, 5 позиций (§4)
- [x] Замеры из §5 — ✅ всё, кроме тока на белом и аккумулятора (их на макетке/при разборке)
- [x] ~~Выпаять разъёмы~~ — гнёзда SMD, вместо этого **вилки с кабелей срезаны** 04.09
- [x] **Снять с платы балласты** — ✅ 04.09: `5R6`, 2× `3R3`, `6R8`; промерены 5.6 / 3.4 /
      3.3 / 6.8 Ом. Плата `XKD1621` в пакетик
- [x] Прошить HAA — ✅ 04.09, `fullhaaboot_esp32.bin` 12.18.1, esptool 5.4 через pipx,
      `erase-flash` + `write-flash -fs 2MB -fm dio 0x0`. JSON — `docs/haa-config.json`
- [x] Спарить в Home.app — ✅ 04.09, код `0218-2017`, три имени (см. статус). Уровни на
      GPIO 25/26/27/32 проверены мультиметром без силовой части
- [x] ~~Breadboard~~ → **драйвер сразу спаян на перфборде** — ✅ 08.09, по схеме §3, своя
      раскладка (не по `docs/wiring.html`). ESP32 питается с +5/GND платы через ноги C1, USB не
      используется. Лампа и мотор работают из Home.app
- [x] **Лазер звёзд** — ✅ 08.09: разъём `JG` донора оказался лазером, подключён в параллель
      мотору на сток Q-M через `R11` 10 Ом с донора. **Решение 09.09: так и остаётся**, пятый
      ключ не ставим
- [ ] **Конфиг HAA: эффекты** (`"fx"` + виртуальные плитки) — залить по Wi-Fi через режим
      настройки, перепрошивка не нужна. Это последняя задача проекта, [issue #3](https://github.com/rudnik275/astronaut-lamp/issues/3)
- [ ] ~~Печатная плата `hardware/`~~ — спроектирована, **не заказывается** (решение 09.09),
      лежит как опция
- [ ] ~~Резисторы 2 Вт и IRLZ44N на РКС~~ — не нужны, пересборка отменена
- [ ] Ранец, USB-C гнездо, укладка в корпус — по желанию, проект в рабочем состоянии и без них

⚠️ При прошивке по USB **отключать внешние 5 В с VIN**. На ESP32 DevKit v1 от USB к
5В-шине обычно стоит защитный диод, так что риск ниже, чем был бы на NodeMCU, — но
встречное питание двух источников всё равно не нужно, правило сохраняем. В бутлоадер
DevKit обычно входит сам (esptool дёргает DTR/RTS); если не вошёл — зажать кнопку
`BOOT` при старте прошивки.

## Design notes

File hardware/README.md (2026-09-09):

# astro-driver v1 — печатная плата драйвера лампы-космонавта

ESP32-WROOM-32E прямо на плате, USB-C для питания и прошивки, пять ключей (R, G, B,
мотор, лазер), посадочные места под выводные балласты 2 Вт и электролит 1000 µF.
Плата 60 × 47 мм, двухслойная, антенна модуля свисает за верхний край на 3 мм.
Проект KiCad 10 **генерируется скриптами** из одного описания (`design.py`): и схема, и
плата рождаются из одного списка цепей, и их совпадение проверяется автоматически.

## Что в папке

| Файл | Что это |
|---|---|
| `design.py` | детали (с кодами LCSC для сборки на JLCPCB), цепи, координаты — единственный источник правды |
| `build_kicad.py` | плата: расстановка, цепи, контур, предразводка USB-C, зоны земли, BOM/CPL |
| `build_schematic.py` | схема на метках + сверка нетлиста схемы с `design.NETS` |
| `run.sh` | весь цикл: сборка → проверки → Freerouting → заливка → DRC → гербер/рендер/PDF |
| `lib/astro.pretty/` | копия посадочного места ESP32-WROOM-32 с courtyard по корпусу и отверстиями термопада 0.3 мм |
| `out/astro-driver.kicad_pro` `.kicad_sch` `.kicad_pcb` | проект: открывать в KiCad 10 (`~/Applications/KiCad/KiCad.app`) |
| `out/astro-driver-gerbers.zip` | гербер + сверловка для JLCPCB |
| `out/jlc-bom.csv`, `out/jlc-cpl.csv` | BOM и координаты для сборки (только SMD) |
| `out/astro-driver-schematic.pdf` | схема в PDF |
| `out/render-top.png`, `out/render-bottom.png` | рендер платы |

## Состояние

- Нетлист схемы = `design.NETS`: 36 цепей, расхождений нет.
- ERC: два предупреждения «power output ↔ power output» (V3 CH340C соединён с 3.3 В по даташиту — это норма для питания CH340C от 3.3 В).
- DRC после трассировки: 0 неразведённых связей, электрических нарушений нет. Остались
  косметические: шелкография модуля пересекает край платы (антенна свисает), пара
  наложений подписей.
- **Не проверено на живом железе.** Первую партию считать прототипом.

## Схема, коротко

- Питание 5 В с USB-C (площадка A4/B9, два контакта, до 2.5 А; вторая площадка VBUS
  намеренно пустая — между ними идут D+/D−/CC) или с разъёма `5V IN` от гнезда в стенке.
  CC1/CC2 через 5.1 кОм на землю, чтобы работал любой кабель и PD-зарядник.
- AMS1117-3.3 → 3.3 В для модуля и CH340C. Индикатор 3.3 В — красный светодиод.
- CH340C (без кварца) + два S8050 — автосброс EN/IO0 при прошивке, как на DevKit.
  Кнопки EN и BOOT выводные, необязательны.
- Каналы: GPIO25/26/27 → R/G/B, GPIO32 → мотор, GPIO33 → лазер. На каждом: 220 Ом в
  затвор, 10 кОм на землю, ключ AO3400A (SOT-23, logic-level, 5.7 А).
- Балласты выводные 2 Вт (`RR` 5R6, `RG`/`RB` 3R3, `RM` 6R8 мотор, `RL` 10R лазер), SS14
  параллельно мотору, 1000 µF по 5 В.
- Разъёмы 2.54 мм под пайку проводов или штыри: `J2` LED `V G R B` (порядок как на
  доноре), `J3` мотор (`1` ключ, `2` +5), `J4` лазер (`1` +5, `2` ключ — полярный!),
  `J5` 5V IN (`1` +5, `2` GND).

## Заказ на JLCPCB

1. jlcpcb.com → Order now → загрузить `out/astro-driver-gerbers.zip`. 2 слоя, 60 × 47 мм,
   5 шт (минимум), толщина 1.6, цвет любой, HASL. Остальное по умолчанию.
2. Включить **PCB Assembly**: Economic, Top side, 2 или 5 шт. Загрузить `jlc-bom.csv` и
   `jlc-cpl.csv`. В списке деталей проверить, что каждая позиция нашлась по коду LCSC и есть
   в наличии; при замене брать тот же корпус.
3. В предпросмотре расстановки **проверить поворот** ESP32, CH340C, AMS1117, USB-C,
   диода и светодиода: у KiCad и JLCPCB разные нулевые углы, JLCPCB даёт покрутить прямо
   в окне.
4. Выводные детали (балласты, электролит, гребёнки, кнопки) завод не ставит, паяются
   руками; они в BOM для сборки не входят.

Что не монтируется на заводе и нужно иметь: 2 Вт резисторы 3R3 ×2, 5R6, 6R8, 10R;
электролит 1000 µF 16 В; гребёнка 2.54 на 4 + 2 + 2 + 2 контакта (или просто провода);
две тактовые кнопки 6 × 6 (необязательно).

## Цена, ориентировочно (сентябрь 2026, проверить в калькуляторе JLCPCB)

| Вариант | Состав | Итого |
|---|---|---|
| Голая плата, 5 шт | плата ~2 $ + доставка в Украину 12–20 $ | **~15–22 $** за 5 плат, детали покупать и паять самому (модуль ESP32, CH340C, USB-C с шагом 0.5 мм — руками тяжело) |
| Со сборкой SMD, 2 шт | плата 2 $ + сборка 8 $ + два «extended»-компонента 6 $ + детали ~4.5 $/шт + доставка 15–25 $ | **~40–50 $** |
| Со сборкой SMD, 5 шт | то же + детали на 5 плат | **~55–70 $**, ~12 $ за плату |

Таможня не задевается: сумма ниже 150 €. Рекомендуется вариант со сборкой: всё сложное
паяет завод, дома остаются пять резисторов, конденсатор, гребёнки и провода.

## Пересобрать

```
sh hardware/run.sh all
```

Нужны: KiCad 10 в `~/Applications/KiCad/KiCad.app`, `brew install openjdk`, Freerouting jar
(`FREEROUTING_JAR=/путь/freerouting-2.4.1.jar`). Правки только в `design.py`; после
`run.sh all` смотреть строку «неразведённых связей» и DRC.

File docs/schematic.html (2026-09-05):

astronaut-lamp · драйвер на макетке · 04.09.2026

# Схема лампы-космонавта

Три ШИМ-канала на RGB-светодиод с общим анодом и один ключ на мотор проектора. Собирается на breadboard, корпус потом.

Плата

ESP32-WROOM-32, та что заказана

NodeMCU электрически подошла бы (логика тоже 3.3 В, IRLZ44N от неё открывается), но у ESP8266 нет аппаратного ШИМ: HAA крутит его программно, максимум 2 кГц, тем же ядром, что держит Wi-Fi и HomeKit. Это риск мерцания, ради яркости всё и затевалось. У ESP32 ШИМ аппаратный (LEDC, 5 кГц по умолчанию). NodeMCU остаётся под CO₂-птичку.

Прошивка

Сначала, на голой плате

Прошивать по USB надо без 5 В на VIN, а на пустой плате это само собой. Заодно проверяется, что плата живая, а конфиг правильный: уровни на GPIO меряются мультиметром ещё до того, как подключён хоть один транзистор. Подтяжки 10 кОм держат все ключи закрытыми при загрузке, так что порядок безопасен в обе стороны.

## Принципиальная схема

ШИМ не инвертирован: «1» на затворе открывает ключ и зажигает канал. Линии R и G перекрещиваются, потому что на разъёме донора пины идут в порядке V G R B, а GPIO 25/26/27 назначены как R/G/B. Балласты подтверждены прозвонкой донора 04.09.2026: 5R6 в красном, 3R3 в зелёном и синем. В цепи мотора на доноре стоит R18 = 6.8 Ом (рядом с D1 и Q1), он переезжает в новый драйвер вместе с балластами.

## Соединения на breadboard

Шина «+» макетки это +5 В от адаптера, шина «−» это общий GND. Ноги IRLZ44N считаются надписью к себе: 1 затвор, 2 сток, 3 исток.

Откуда | Куда | Через что
Питание
Адаптер +5 В | шина «+» | USB-кабель с разделанным концом или USB-breakout
Адаптер GND | шина «−»
ESP32 GND | шина «−» | обязательно, иначе GPIO не имеют общей точки с ключами
C1 1000 µF | «+» на шину «+», «−» (полоска) на шину «−» | рядом с местом входа питания
ESP32 VIN | никуда | на столе ESP32 питается от USB ноутбука
Канал R · GPIO25 · Q-R
GPIO25 | затвор Q-R (нога 1) | 220 Ω
Затвор Q-R | шина «−» | 10 kΩ
Исток Q-R (нога 3) | шина «−»
Сток Q-R (нога 2) | провод R светодиода | балласт 5R6 с донора
Канал G · GPIO26 · Q-G
GPIO26 | затвор Q-G (нога 1) | 220 Ω
Затвор Q-G | шина «−» | 10 kΩ
Исток Q-G (нога 3) | шина «−»
Сток Q-G (нога 2) | провод G светодиода | балласт 3R3 с донора
Канал B · GPIO27 · Q-B
GPIO27 | затвор Q-B (нога 1) | 220 Ω
Затвор Q-B | шина «−» | 10 kΩ
Исток Q-B (нога 3) | шина «−»
Сток Q-B (нога 2) | провод B светодиода | балласт 3R3 с донора
Общий анод
Провод V светодиода (общий анод) | шина «+» | напрямую
Мотор · GPIO32 · Q-M
GPIO32 | затвор Q-M (нога 1) | 220 Ω
Затвор Q-M | шина «−» | 10 kΩ
Исток Q-M (нога 3) | шина «−»
Сток Q-M (нога 2) | первый провод мотора | резистор 6R8 с донора (R18), как стоял в родной цепи мотора
Второй провод мотора | шина «+» | полярность мотора неважна, перестановка меняет направление вращения
D1 1N5819 | полоска (катод) на шину «+», анод на сток Q-M | параллельно мотору

Если DevKit оказался 38-контактным, на одну макетку он не встанет: положи его рядом и тяни к макетке dupont мама-папа. На 30-контактном DevKit V1 пины 32, 33, 25, 26, 27 идут подряд на одной стороне, сверь по шелкографии.

## Пинауты

### IRLZ44N, корпус TO-220

1. G затвор ← 220 Ω от GPIO, и 10 kΩ на GND
2. D сток → нагрузка (балласт или мотор). Спинка тоже сток
3. S исток → GND

Четыре TO-220 рядом на макетке: спинки не должны касаться друг друга, у каждого свой сток.

### Провода светодиода и мотора

Вилки срезаны (шаг 2.0 мм, dupont не входил). Концы зачистить на 5–6 мм, скрутить, залудить с флюсом: лужёный конец входит в макетку как ножка детали. Если провод толстый или лохматится, припаять его к штырьку от dupont.

VRGB светодиод, 4 провода · V = +5 В, общий анод

MM мотор, 2 провода, полярность неважна

- Найти V. Мультиметр в режим диода (▷|, предел 2K), красный щуп на один провод, чёрный по очереди на три остальных. Провод, при котором хотя бы один канал даёт число или светодиод тлеет, и есть V. Глухо на всех, переставить красный на следующий провод.
- Различить R, G, B. На ESP32 от USB: провод V на пин 5V/VIN через 220 Ом, остальные по очереди на GND. Цвет виден глазом, ток около 13 мА, без балласта это безопасно. Подписать провода маркером или скотчем.
- Балласты подтверждены прозвонкой: 5R6 (R13) в красный канал, 3R3 (R14, R12) в зелёный и синий.
- Мотор: 6R8 (R18 с донора) в разрыв между стоком Q-M и проводом мотора. Без него мотор получит все 5 В и будет крутиться быстрее, чем задумано.
- Все четыре резистора SMD, в макетку их не воткнуть: припаять поперёк двух соседних штырьков гребёнки или к обрезкам ножек, тогда встанут как обычные выводные.

## Порядок работ

1. Прошить голую плату. К ESP32 ничего не подключено, только USB от ноутбука. Бинарник fullhaaboot_esp32.bin из релиза 12.18.1 репозитория RavenSystem/haa (для одноядерной платы fullhaaboot_esp32_1.bin, ядра покажет первая команда).

python3 -m esptool flash_id
python3 -m esptool erase_flash
python3 -m esptool -b 460800 --before=default_reset --after=hard_reset write_flash -fs 2MB -fm dio 0x0 fullhaaboot_esp32.bin
  Если esptool не стоит: python3 -m pip install esptool. Если плата не вошла в режим прошивки сама, зажать BOOT на время старта команды.
2. Первичная настройка по Wi-Fi. На айфоне подключиться к сети HAA-XXXXXX, открыть http://192.168.4.1:4567. Указать домашнюю сеть 2.4 ГГц, вставить JSON ниже, Flash mode выбрать DIO, Save.
  Дальше плата сама скачивает основную прошивку с GitHub, поэтому в этой Wi-Fi нужен интернет. Занимает около 10 минут, плата перезагрузится сама.
3. Спарить и проверить уровни без силовой части. Home.app → добавить аксессуар → «Всё равно добавить». Мультиметр на V⎓, чёрный щуп на GND платы:
  красный 100 % → на GPIO25 около 3.3 В, 0 % → 0 В, 50 % → около 1.6 В (прибор показывает среднее ШИМ). То же для 26 и 27. «Звёздное небо» вкл → на GPIO32 3.3 В. Если цвет в Home.app и номер пина не совпали, поправить порядок в "g" сейчас.
4. Собрать макетку по таблице. USB от ESP32 отключён, адаптер в розетку не воткнут. Пройти чеклист ниже.
5. Включить. Сначала адаптер на шину +5 В, потом USB в ESP32. Проверить каждый цвет по отдельности, потом белый и мотор. Если красный с зелёным поменялись местами, поменять номера в "g", провода не трогать.
6. Замерить ток на белом. Мультиметр на A⎓ 10 A в разрыв +5 В от адаптера. Это ответ, потянет ли адаптер 2 А лампу вместе с мотором и ESP32, и нужен ли другой номинал балластов.

## Конфиг HAA

Wi-Fi в JSON не входит, она задаётся на той же странице настройки. Элемент io для аппаратного ШИМ: [[пины], 9, подтяжка, начальное значение, режим ШИМ, таймер]; для простого выхода: [[пин], 2, подтяжка, начальное значение]. Частота аппаратного ШИМ по умолчанию 5 кГц, ключ "y" можно не задавать.

{
  "c": {
    "io": [ [[25,26,27], 9, 0, 0, 0, 0], [[32], 2, 0, 0] ]
  },
  "a": [ {
    "t": 30,
    "g": [25, 26, 27],
    "es": [ { "t": 1, "0": { "r": [[32, 0]] }, "1": { "r": [[32, 1]] } } ]
  } ]
}

В Home.app получится один аксессуар с двумя плитками: лампа с цветовым кругом и выключатель проектора. Сверено с wiki HAA 04.09.2026: GPIOs-Configuration, Lightbulb, Switches, General-Configuration.

## Перед подачей питания

- В каждом из каналов R, G, B последовательно стоит балласт с донора. Без балласта светодиод не включать.
- В цепи мотора между стоком Q-M и проводом мотора стоит 6R8 с донора.
- У каждого из четырёх затворов есть 10 kΩ на шину «−».
- D1 стоит полоской (катодом) к шине «+», анодом к стоку Q-M.
- C1 стоит полоской (минусом) к шине «−».
- Спинки четырёх IRLZ44N не касаются друг друга.
- VIN ESP32 не подключён к шине «+», плата питается от USB.
- GND ESP32 сидит на шине «−» вместе с GND адаптера.
- Провод V светодиода (общий анод) на шине «+», а не на стоке. Остальные три провода опознаны и подписаны.

## Укладка в ранец 63 × 52 × 20 мм

Один слой, без бутерброда: ESP32 со срезанной гребёнкой вдоль длинной стенки, рядом полоска перфборда 24 × 58 мм с драйвером. Всё в масштабе, размеры деталей реальные: DevKit на 30 пинов 51 × 25.4, TO-220 плашмя 10.2 × 15.5, конденсатор 1000 µF лёжа 10 × 16.

Слева вид сверху в масштабе, справа разрез. Запас по высоте 5 мм даже над стоящими 10 кОм, по длине 3 мм, по ширине около 2 мм между ESP32 и перфбордом. Если DevKit на 38 пинов (55 × 28 мм), полоска перфборда сужается до 21 мм, конденсатор тогда ставить не на боку, а лёжа вдоль, всё остальное так же.

- Перфборд обрезать до 9 × 23 отверстий: процарапать ножом по ряду отверстий с двух сторон и переломить об край стола.
- ESP32 антенной к торцевой стенке, USB к другой. Под платой полоска каптона, по углам четыре капли термоклея.
- TO-220 класть плашмя спинкой к наружной стенке: спинка это сток, между соседними зазор 1.5 мм, и никакого металла рядом.
- 10 кОм ставить стоя, 220 Ом лёжа, балласты на двух штырьках стоя, C1 на боку в торце платы, D1 под ним.
- Перфборд на дно через квадрат вспененного двустороннего скотча, жгут из 6 проводов к ESP32 прихватить каплей клея у обеих плат.
- После укладки, до крышки: прозвонка +5 В ↔ GND и каждого GPIO ↔ +5 В, затем включение с открытой крышкой.

Источник схемы и решений: README проекта astronaut-lamp, §3 и §6. Родную плату XKD1621 после выпайки разъёмов и балластов убрать в пакетик, путь обратим.

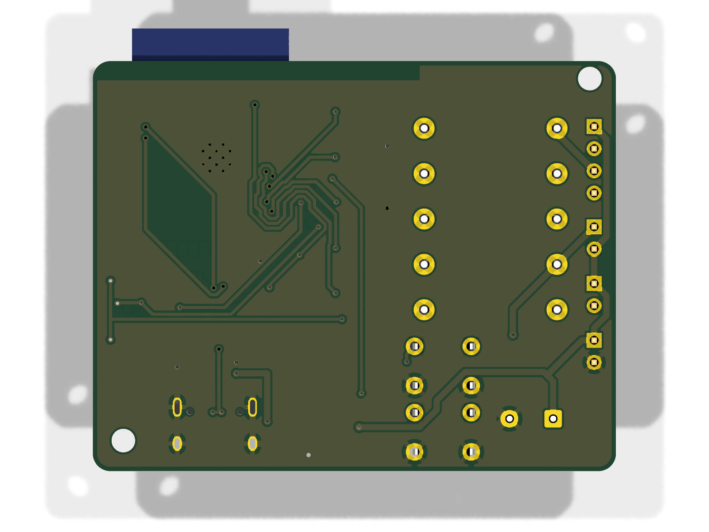
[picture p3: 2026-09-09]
hardware/out/render-bottom.png

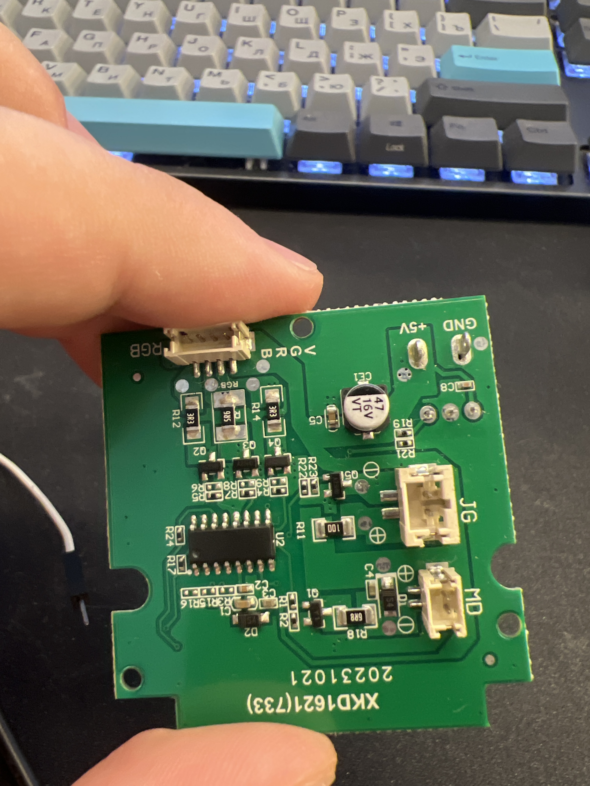
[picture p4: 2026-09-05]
photos/board-XKD1621-clean.jpg

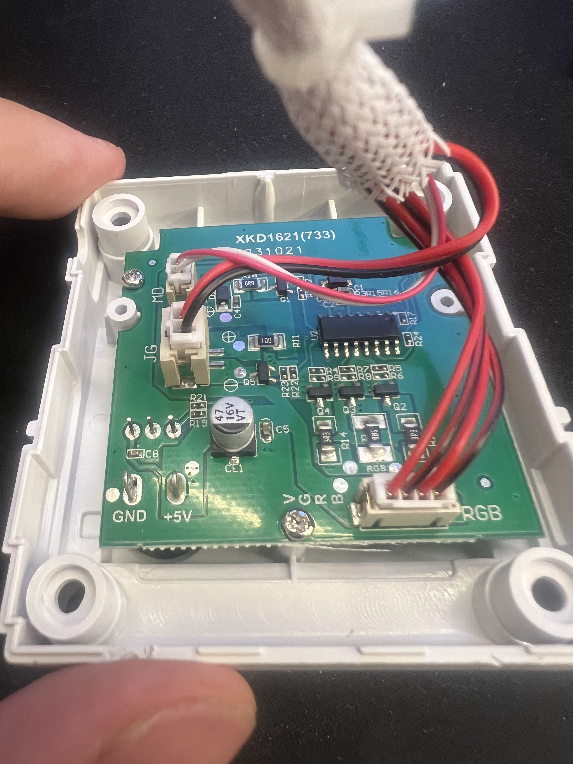
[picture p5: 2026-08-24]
photos/board-XKD1621.jpeg

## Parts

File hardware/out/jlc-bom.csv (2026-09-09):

Comment | Designator | Footprint | LCSC Part #
10uF | C2,C3,C4 | C_0805_2012Metric | C15850
100nF | C5,C7,C8 | C_0603_1608Metric | C14663
1uF | C6 | C_0603_1608Metric | C15849
SS14 | D1 | D_SMA | C2480
LED red | D2 | LED_0603_1608Metric | C2286
USB-C 16p | J1 | USB_C_Receptacle_HRO_TYPE-C-31-M-12 | C165948
AO3400A | Q1,Q2,Q3,Q4,Q5 | SOT-23 | C20917
S8050 | Q6,Q7 | SOT-23 | C2146
5.1k | R1,R2 | R_0603_1608Metric | C23186
10k | R3,R4,R5,R6,RP1,RP2,RP3,RP4,RP5 | R_0603_1608Metric | C25804
1k | R7 | R_0603_1608Metric | C21190
220R | RG1,RG2,RG3,RG4,RG5 | R_0603_1608Metric | C22962
ESP32-WROOM-32E | U1 | ESP32-WROOM-32_body | C701341
CH340C | U2 | SOIC-16_3.9x9.9mm_P1.27mm | C84681
AMS1117-3.3 | U3 | SOT-223-3_TabPin2 | C6186

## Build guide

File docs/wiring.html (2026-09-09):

astronaut-lamp · драйвер на перфборде 3×7 · 08.09.2026

# Монтаж лампы-космонавта

Куда идёт каждый провод и что с чем спаять на перфборде 10 × 24 отверстия. Картинки вместо схемы: вид сверху, где стоят детали, и вид снизу, где паять.

Ноги двух соединённых деталей

В соседние отверстия, соединять загнутой ногой снизу

Каждая нога в своё отверстие. На стороне пайки одну ногу загибаешь плашмя до пятачка соседа и паяешь в обеих точках. Две ноги в одно отверстие не совать.

Проводов снаружи

14, все заходят сверху в ряды J и H

6 к ESP32, 4 к светодиоду, 2 к мотору, 2 от питания 5 В. Номер провода одинаковый на всех картинках и в таблице.

## Как читать плату

Плата лежит длинной стороной горизонтально. Ряды A…J считаются от края, к которому смотрят спинки IRLZ44N (в корпусе это наружная стенка), ряд J ближе к ESP32. Колонки 1…24 слева направо, если смотреть сверху. Отверстие называется рядом и колонкой: H2 это ряд H, колонка 2.

Первым делом пометь колонку 1 маркером с обеих сторон платы, у ряда A. Снизу плата зеркальна, и без метки легко спаять всё в отражении. Вид снизу на этой странице уже отзеркален: там колонка 24 слева.

- Схема остаётся прежней, со страницы «Схема лампы-космонавта». Одно отличие: 10 кОм стоит с той стороны 220 Ом, где GPIO, а не у затвора. Электрически это то же самое, зато не нужен лишний мост.
- Плата используется целиком, все 10 × 24 отверстия. Поля обрезать позже, под корпус, после пайки платы; отсек ранца тогда считать под 25.4 × 61 мм, а не 24 × 58, как на странице схемы.
- Спинка TO-220 (металл, это сток) ложится на верхние пятачки рядов A–B. Туда ничего не вставлять и снизу через эти ряды ничего не тянуть.

## Карта проводов

ESP32 нарисован сверху, антенной вправо: так шесть нужных пинов оказываются в одном ряду. Положение платы в корпусе может быть любым, карта только про то, какой пин в какое отверстие. На столе провод 6 (VIN) не подключать: ESP32 питается от своего USB, а провода 13 и 14 идут от адаптера 5 В, не от USB-C.

## Вид сверху: где стоят детали

Все резисторы стоят вертикально: нижняя нога в отверстие под корпусом, верхняя загибается вниз в соседнее отверстие, куда показывает линия. У IRLZ44N надпись смотрит вверх, ноги согнуты вниз сразу после широкой части, тогда спинка заканчивается у края платы. Кружок с номером это провод, номера те же, что на карте.

## Вид снизу: что с чем спаять

Зеркально, колонка 24 слева, метка маркером у правого края. Медная линия это нога детали, загнутая плашмя по плате от своего отверстия (точка) до пятачка соседа (кольцо); паять в обеих точках. Толстая линия по ряду G это голый лужёный провод, шина GND; по ряду I справа такая же шина +5 В. Если балласты с донора без ножек, они ложатся SMD-стороной прямо на пятачки I и J снизу, как нарисовано; если ножки уже припаяны, ставь их сверху стоя в те же отверстия.

## Как паять на перфборде

Плата двусторонняя с металлизированными отверстиями: припой затекает насквозь, пятачок есть с обеих сторон и от нагрева не отслаивается. Это прощает многое, кроме одного: любой голый металл, лежащий на пятачке, с ним соединён. Поэтому шина проводом и спинка TO-220 всегда лежат только там, где эта цепь и должна быть.

### нетДве ноги в одно отверстие

Отверстие 1 мм на две ноги не рассчитано: вторая нога входит с натягом или не входит, припой не затекает, а перепаять такую пару потом невозможно, не вынув обе.

### даСоседние отверстия, нога загнута снизу

Обе ноги через свои отверстия. Снизу ногу A прижимаешь плашмя к плате, ведёшь до пятачка B, паяешь у A и у B, лишнее откусываешь после пайки. Нога работает как дорожка, держится намертво. Так сделаны все соединения на виде снизу.

### иногдаПеремычка припоем

Только между двумя соседними пятачками и только с флюсом: припоя нужно много, он норовит стянуться в две отдельные капли. Годится, если забыл оставить ногу длинной. Не основной способ.

### даШина голым проводом

Для GND и +5 В. Кусок голого лужёного провода (обрезок ноги резистора или жила от dupont без изоляции) ложится по ряду снизу, к нему припаивается каждая нога, которой нужна эта цепь. Провод не должен заходить на пятачки чужих рядов.

### даРезистор стоя

Так стоят все 220 Ом и 10 кОм. Нижняя нога прямо в отверстие под корпусом, верхнюю загибаешь на 180° и опускаешь в соседнее отверстие. Занимает две дырки вместо четырёх, а 1-ваттные 10 кОм лёжа просто не поместились бы.

### даSMD-балласт без ножек

Резисторы с донора можно не сажать на ножки: залудить оба пятачка, положить резистор между ними снизу, прогреть торец, пока он не сядет, потом второй. Шаг 2.54 мм для корпуса 1206 и даже 0805 в самый раз.

### Правила, которые экономят переделку

- Ноги откусывать после пайки, не до. Ногу, которая должна лечь мостом к соседу, вообще не откусывать, пока не припаяна в обеих точках.
- Ставить детали от низких к высоким: сначала резисторы, потом диод, потом TO-220, конденсатор и провода последними. Иначе высокие мешают паять низкие.
- Хорошая пайка выглядит как блестящий конус вокруг ноги, припой затёк в отверстие. Матовый шарик, который сидит на ноге и не касается пятачка, надо прогреть ещё раз с флюсом.
- Паяльник 320–350 °C для обычного припоя, 2–3 секунды на точку. Флюс-гель на каждый пятачок, смывать потом не обязательно, но спиртом чище.
- Провода: зачистить 4 мм, скрутить, залудить, вставить сверху, снизу загнуть к соседнему пятачку по карте, припаять. Провод из dupont-шлейфа с откушенным разъёмом для этого в самый раз.
- После каждой цепи прозвонить мультиметром (режим •))) между точками, которые должны быть соединены, и между соседними, которые не должны. Особенно между рядами G и H под TO-220: там три ноги подряд с шагом 2.54.

## Порядок пайки

1. Разложить всё без пайки.
  Вставить четыре IRLZ44N в ряд H, согнув ноги вниз на 4 мм от корпуса: спинка должна заканчиваться у края ряда A, не дальше 1 мм за краем. Приложить конденсатор на бок в колонках 21–24: его ноги должны доставать до H22 и H24. Если у тебя DevKit на 38 пинов или конденсатор длиннее 17 мм, скажи, раскладку сдвину.
2. Пометить колонку 1 маркером с обеих сторон и один раз сверить: вид снизу на этой странице зеркальный, метка там справа.
3. Резисторы каналов, по одному блоку за раз.
  Блок Q-R это колонки 1–5, Q-G 6–10, Q-B 11–15, Q-M 16–20. В каждом: 220 Ом стоя в I(c+1), верхняя нога в J(c+1), припаять, откусить. 10 кОм стоя в I(c), верхняя в J(c): верхнюю ногу загнуть вправо к J(c+1) и припаять к ноге 220; нижнюю ногу не откусывать, а загнуть вверх через H(c) до G(c), она станет отводом на шину GND. Балласт: SMD снизу между I(c+3) и J(c+3), либо с ножками стоя сверху в те же отверстия. Здесь c это первая колонка блока.
4. IRLZ44N.
  Ноги в H(c+1), H(c+2), H(c+3), надпись вверх, спинка к ряду A. Снизу: ногу G загнуть вниз к I(c+1) и припаять к 220; ногу D загнуть вниз к I(c+2) и дальше вправо к I(c+3), припаять к балласту; ногу S загнуть вверх к G(c+3). Пропаять и в родных отверстиях ряда H.
5. Правый край.
  D1 стоя: анод (нога без полоски) в I20, полоска сверху, катод дугой в I21; анод снизу загнуть вниз к J20. C1 на бок: плюс в H22, минус (полоска на корпусе) в H24; снизу плюс загнуть вниз к I22, минус вверх к G24.
6. Шины.
  Голый провод по ряду G снизу от колонки 1 до 24, припаять к каждому загнутому концу, который на него ложится: G1 G4 G6 G9 G11 G14 G16 G19 G24. Второй кусок по ряду I от I21 до I24, припаять к катоду D1 и к загнутому плюсу C1.
7. Провода по карте.
  Все сверху, каждый снизу загибается к соседнему пятачку, как в таблице. Провода 5 и 14 (GND) ложатся на шину G, провода 6, 10, 12, 13 (+5) на шину I. Провода к ESP32 пока с dupont-мамой на конце, чтобы снимать с пинов; в корпусе, когда гребёнка будет срезана, припаять к плате.
8. Прозвонка, потом питание.
  Чеклист ниже. Включать по порядку со страницы схемы: сначала адаптер на +5, потом USB в ESP32, каждый цвет отдельно, потом белый, потом мотор.

## Перед подачей питания

- Между шиной G (GND) и шиной I (+5) прибор не пищит. Между любым пятачком ряда J в колонках 3, 8, 13, 18 (GPIO) и шиной +5 тоже.
- В каждом блоке нога S (третья слева) звонится на шину G, нога G (первая) не звонится ни на G, ни на +5.
- Метка маркером совпала: провод 1 с пина D25 пришёл в третью колонку от метки, а не в двадцать вторую.
- D1: полоска смотрит на +5 (нога в I21), анод на мотор. C1: полоска на корпусе у ноги в H24, то есть на GND.
- Балласты стоят во всех четырёх блоках: 5R6 в колонке 4, 3R3 в 9 и 14, 6R8 в 19. Без балласта светодиод не включать.
- Спинки IRLZ44N не касаются друг друга и не заходят на пятачки правее колонки 20.
- На столе: провод 6 (VIN) не подключён, провод 5 (GND ESP32) подключён обязательно.

Схема и решения: README проекта astronaut-lamp §3 и docs/schematic.html. Раскладка на этой странице генерируется из одного списка соединений; статус проверки связей выводится под видом снизу.

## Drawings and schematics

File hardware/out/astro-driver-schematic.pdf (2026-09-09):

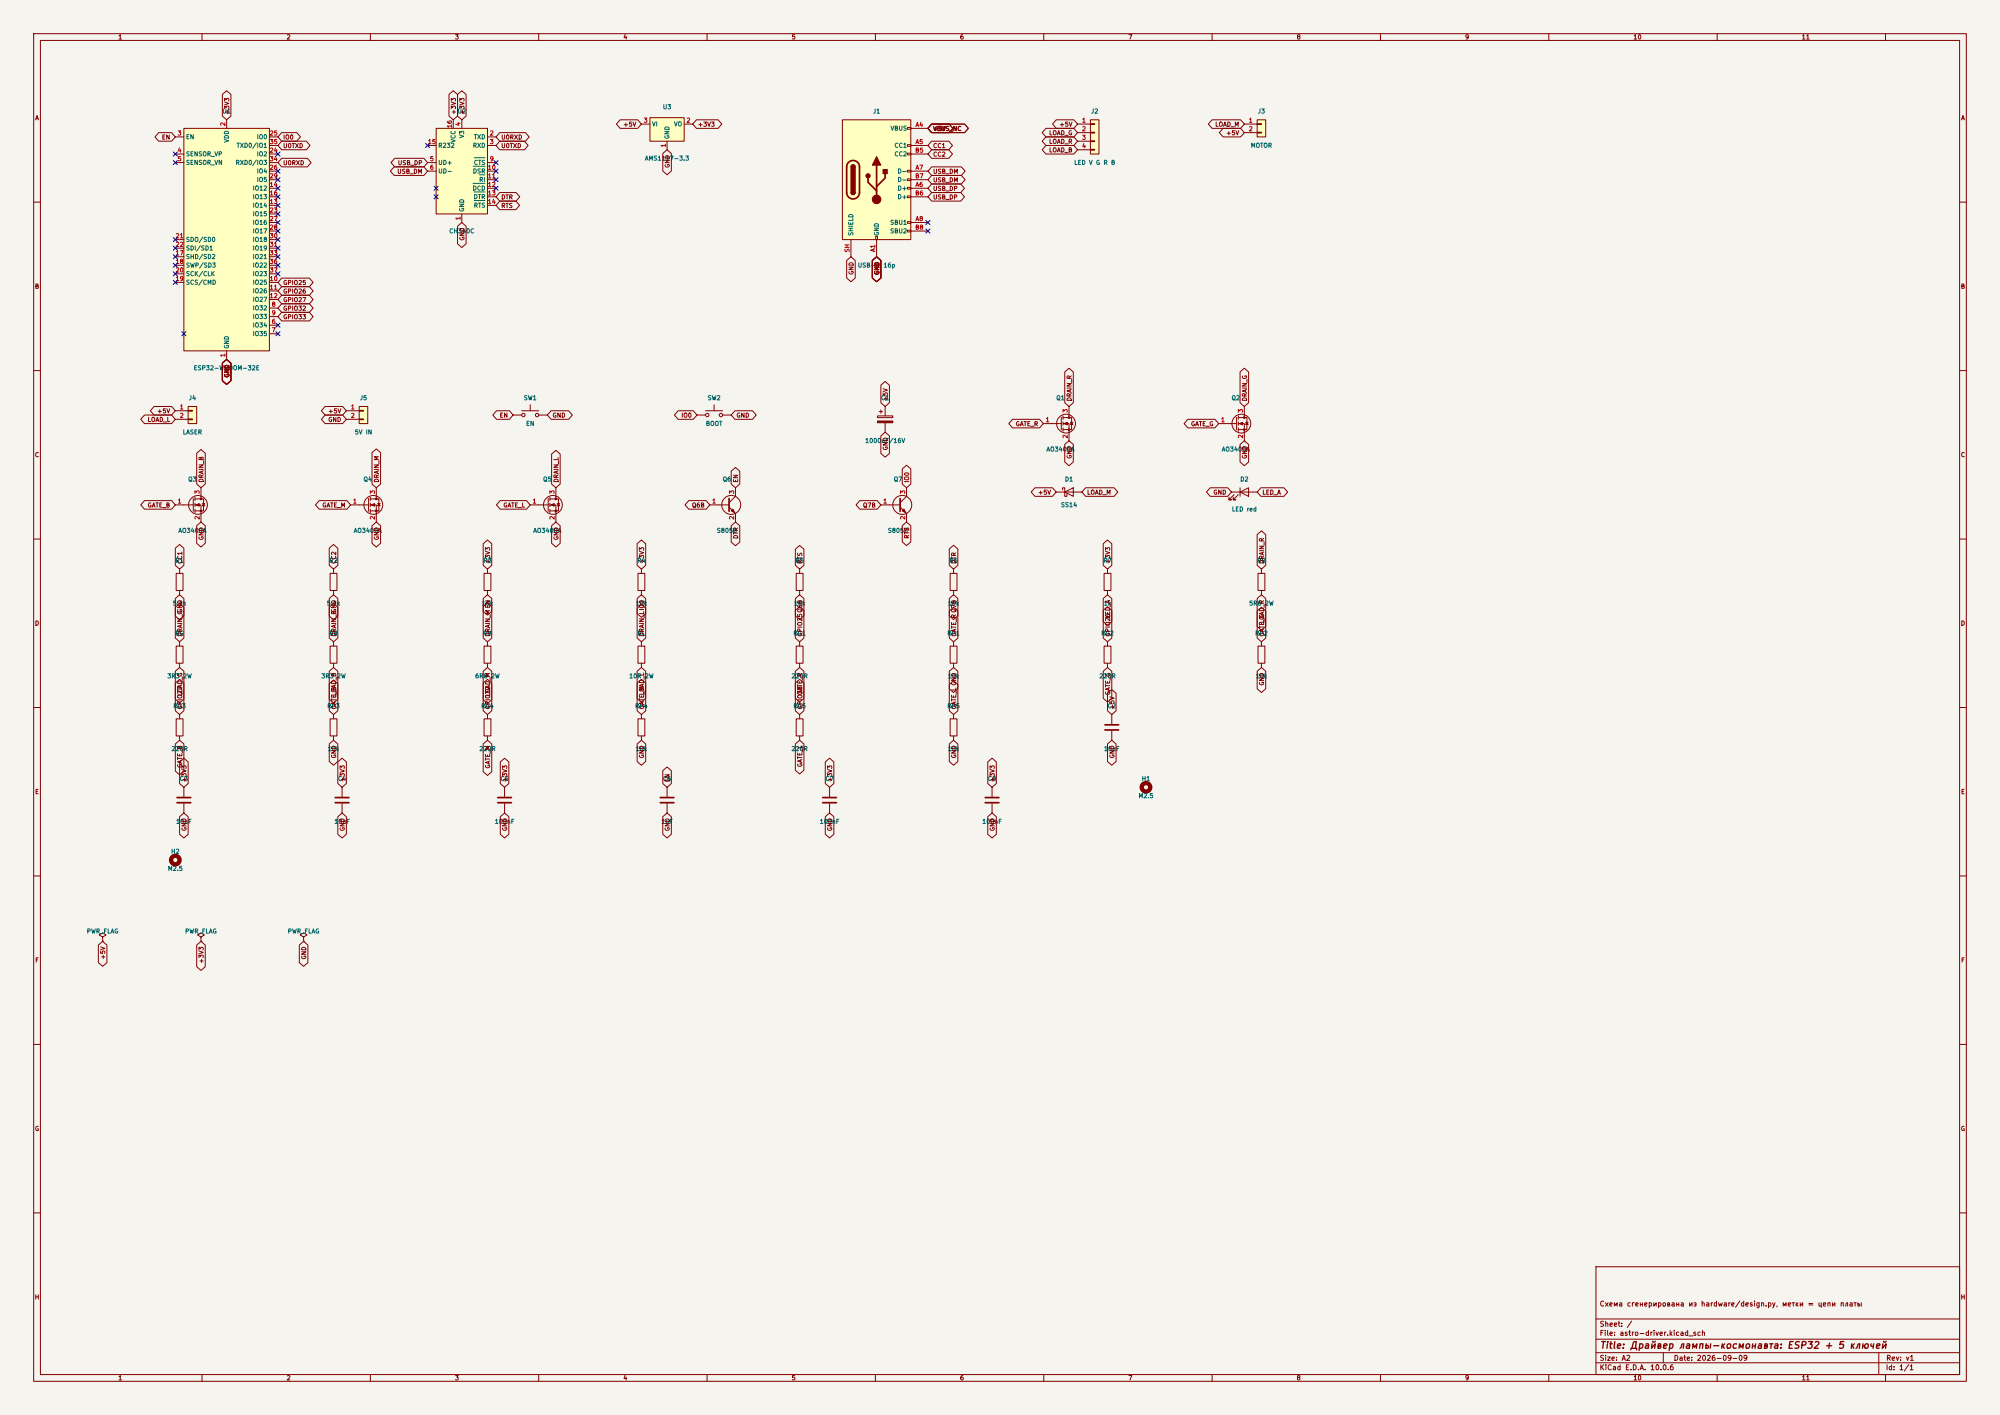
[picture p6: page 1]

4 UD+ 5 UD- 6 CTS 9 DSR 10 RI 11 DCD 12 DTR 13 RTS 14 R232 15 VCC 16 U2 CH340C

Схема сгенерирована из hardware/design.py, метки = цепи платы GND

Sheet: /
File: astro-driver.kicad_sch
Title: Драйвер лампы-космонавта: ESP32 + 5 ключей

Size: A2 | Rev: v1
KiCad E.D.A. 10.0.6 | Id: 1/1

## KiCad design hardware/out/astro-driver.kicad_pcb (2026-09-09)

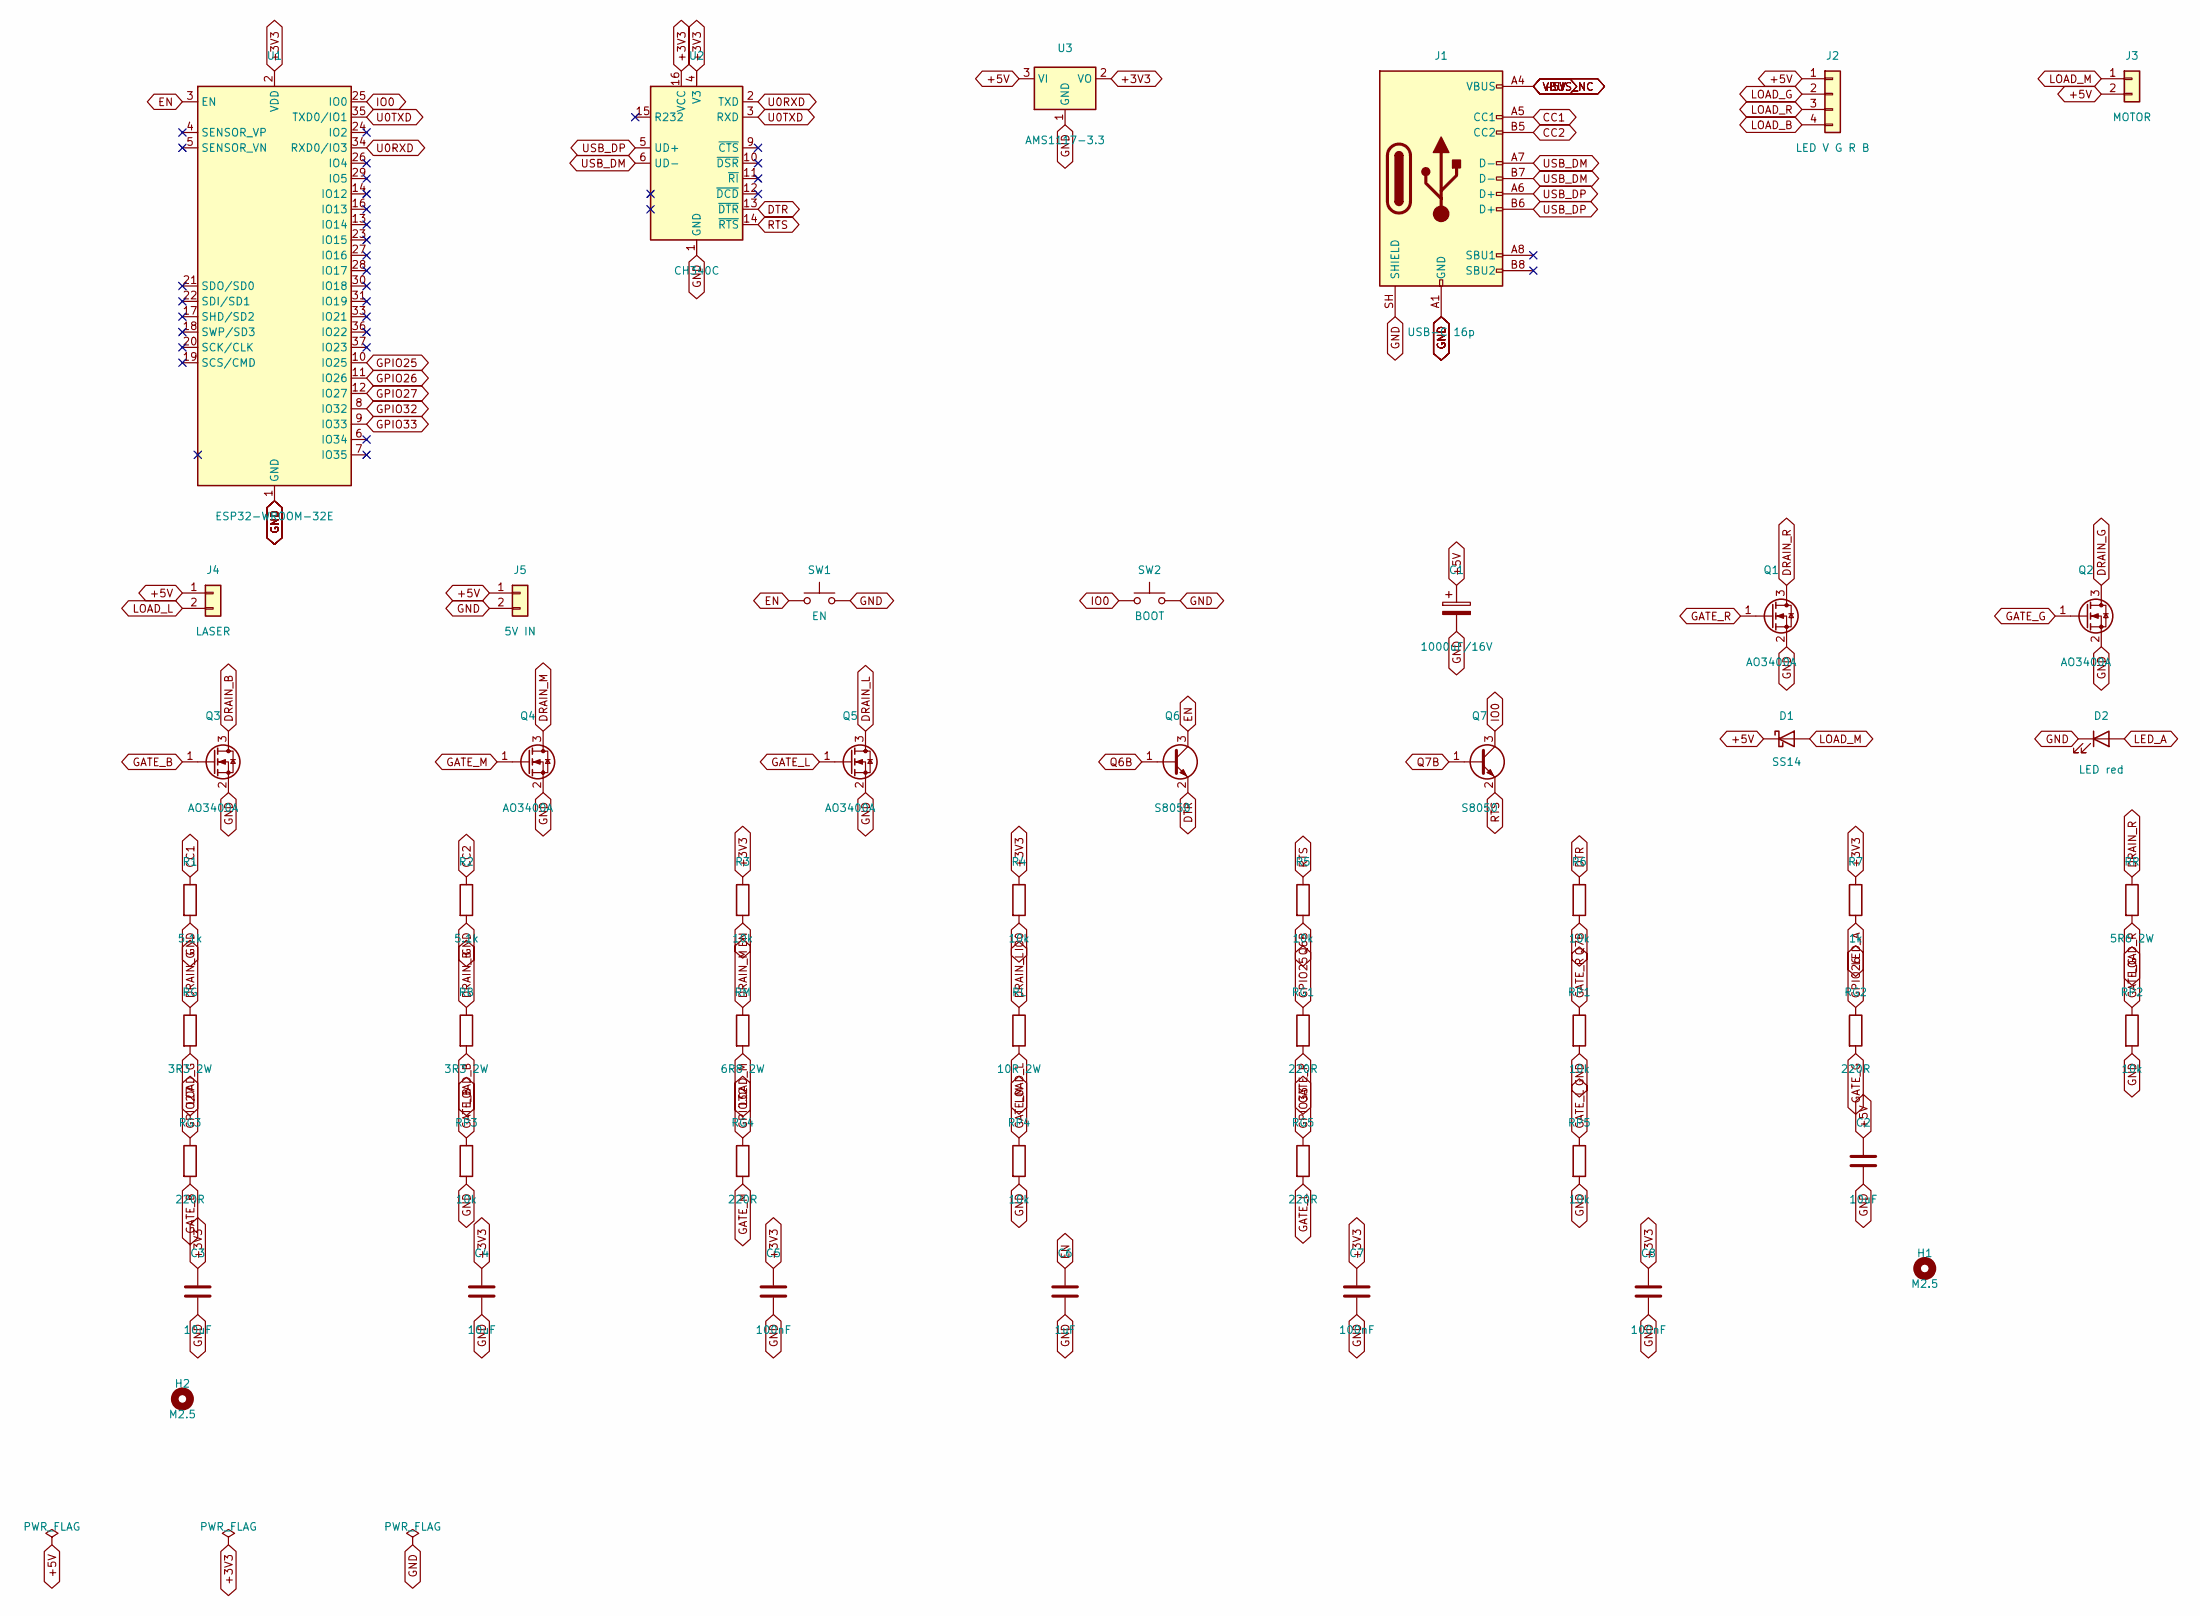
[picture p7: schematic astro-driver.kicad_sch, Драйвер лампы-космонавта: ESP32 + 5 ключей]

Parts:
C1: 1000uF/16V; CP_Radial_D10.0mm_P5.00mm
C2, C3, C4: 10uF; C_0805_2012Metric; LCSC C15850
C5, C7, C8: 100nF; C_0603_1608Metric; LCSC C14663
C6: 1uF; C_0603_1608Metric; LCSC C15849
D1: SS14; D_SMA; LCSC C2480
D2: LED red; LED_0603_1608Metric; LCSC C2286
H1, H2: M2.5; MountingHole_2.7mm_M2.5
J1: USB-C 16p; USB_C_Receptacle_HRO_TYPE-C-31-M-12; LCSC C165948
J2: LED V G R B; PinHeader_1x04_P2.54mm_Vertical
J3: MOTOR; PinHeader_1x02_P2.54mm_Vertical
J4: LASER; PinHeader_1x02_P2.54mm_Vertical
J5: 5V IN; PinHeader_1x02_P2.54mm_Vertical
Q1, Q2, Q3, Q4, Q5: AO3400A; SOT-23; LCSC C20917
Q6, Q7: S8050; SOT-23; LCSC C2146
R1, R2: 5.1k; R_0603_1608Metric; LCSC C23186
R3, R4, R5, R6: 10k; R_0603_1608Metric; LCSC C25804
R7: 1k; R_0603_1608Metric; LCSC C21190
RB: 3R3 2W; R_Axial_DIN0414_L11.9mm_D4.5mm_P15.24mm_Horizontal
RG: 3R3 2W; R_Axial_DIN0414_L11.9mm_D4.5mm_P15.24mm_Horizontal
RG1, RG2, RG3, RG4, RG5: 220R; R_0603_1608Metric; LCSC C22962
RL: 10R 2W; R_Axial_DIN0414_L11.9mm_D4.5mm_P15.24mm_Horizontal
RM: 6R8 2W; R_Axial_DIN0414_L11.9mm_D4.5mm_P15.24mm_Horizontal
RP1, RP2, RP3, RP4, RP5: 10k; R_0603_1608Metric; LCSC C25804
RR: 5R6 2W; R_Axial_DIN0414_L11.9mm_D4.5mm_P15.24mm_Horizontal
SW1: EN; SW_PUSH_6mm
SW2: BOOT; SW_PUSH_6mm
U1: ESP32-WROOM-32E; ESP32-WROOM-32_body; LCSC C701341
U2: CH340C; SOIC-16_3.9x9.9mm_P1.27mm; LCSC C84681
U3: AMS1117-3.3; SOT-223-3_TabPin2; LCSC C6186

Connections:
+3V3: C3.1, C4.1, C5.1, C7.1, C8.1, R3.1, R4.1, R7.1, U1.2 (VDD), U2.4 (V3), U2.16 (VCC), U3.2 (VO)
CC1: J1.A5 (CC1), R1.1
CC2: J1.B5 (CC2), R2.1
DRAIN_B: Q3.3 (D), RB.1
DRAIN_G: Q2.3 (D), RG.1
DRAIN_L: Q5.3 (D), RL.1
DRAIN_M: Q4.3 (D), RM.1
DRAIN_R: Q1.3 (D), RR.1
DTR: Q6.2 (E), R6.1, U2.13 (~DTR)
EN: C6.1, Q6.3 (C), R3.2, SW1.1, U1.3 (EN)
GATE_B: Q3.1 (G), RG3.2, RP3.1
GATE_G: Q2.1 (G), RG2.2, RP2.1
GATE_L: Q5.1 (G), RG5.2, RP5.1
GATE_M: Q4.1 (G), RG4.2, RP4.1
GATE_R: Q1.1 (G), RG1.2, RP1.1
GND: C1.2, C2.2, C3.2, C4.2, C5.2, C6.2, C7.2, C8.2, D2.1 (K), J1.A1 (GND), J1.A12 (GND), J1.B1 (GND), J1.B12 (GND), J1.SH (SHIELD), J5.2, Q1.2 (S), Q2.2 (S), Q3.2 (S), Q4.2 (S), Q5.2 (S), R1.2, R2.2, RP1.2, RP2.2, RP3.2, RP4.2, RP5.2, SW1.2, SW2.2, U1.1 (GND), U1.15 (GND), U1.38 (GND), U1.39 (GND), U2.1 (GND), U3.1 (GND)
GPIO25: RG1.1, U1.10 (IO25)
GPIO26: RG2.1, U1.11 (IO26)
GPIO27: RG3.1, U1.12 (IO27)
GPIO32: RG4.1, U1.8 (IO32)
GPIO33: RG5.1, U1.9 (IO33)
IO0: Q7.3 (C), R4.2, SW2.1, U1.25 (IO0)
LED_A: D2.2 (A), R7.2
LOAD_B: J2.4, RB.2
LOAD_G: J2.2, RG.2
LOAD_L: J4.2, RL.2
LOAD_M: D1.2 (A), J3.1, RM.2
LOAD_R: J2.3, RR.2
Q6B: Q6.1 (B), R5.2
Q7B: Q7.1 (B), R6.2
RTS: Q7.2 (E), R5.1, U2.14 (~RTS)
U0RXD: U1.34 (RXD0/IO3), U2.2 (TXD)
U0TXD: U1.35 (TXD0/IO1), U2.3 (RXD)
USB_DM: J1.A7 (D-), J1.B7 (D-), U2.6 (UD-)
USB_DP: J1.A6 (D+), J1.B6 (D+), U2.5 (UD+)

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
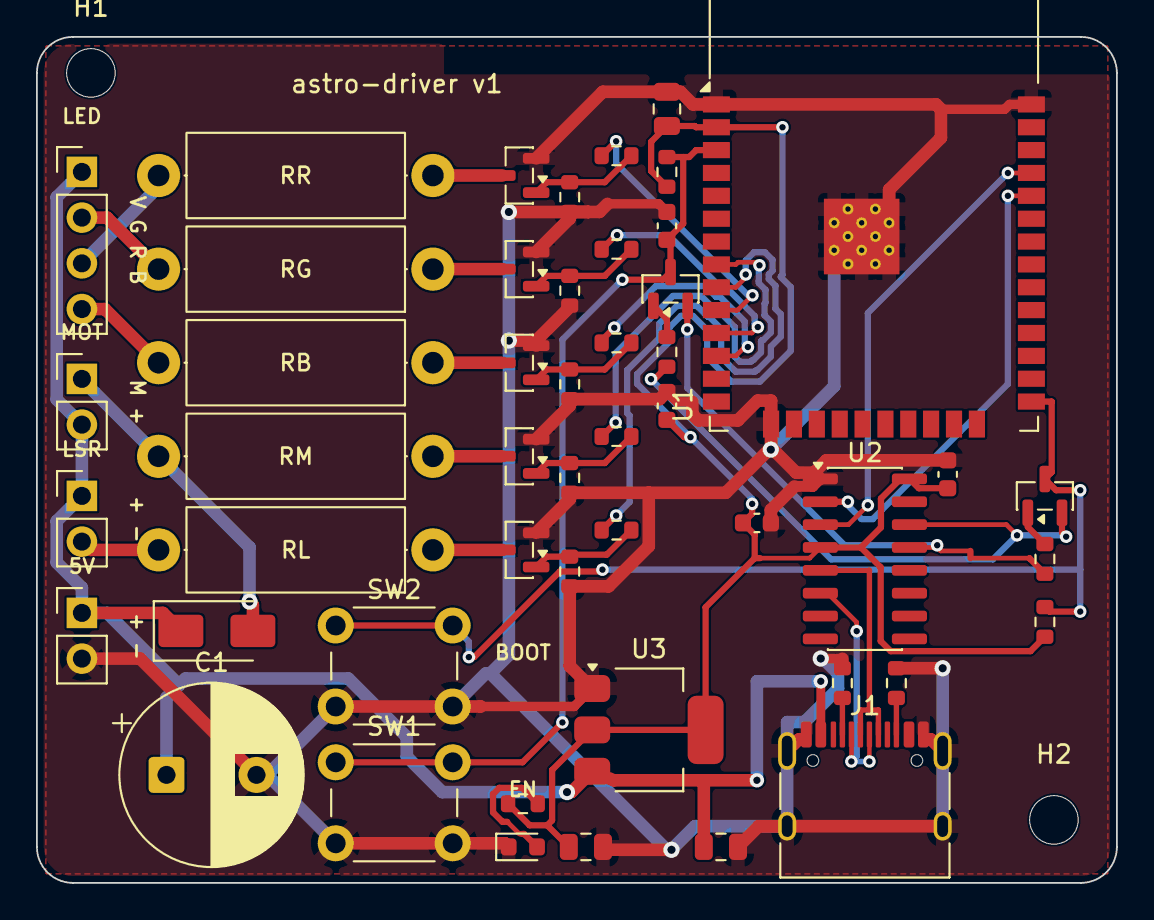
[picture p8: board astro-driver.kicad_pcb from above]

Board: 2 copper layers, 60.0 x 47.0 mm, 51 parts (0 on the bottom side), 37 nets.

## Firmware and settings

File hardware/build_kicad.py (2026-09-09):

"""Генератор платы драйвера лампы-космонавта для KiCad 10.

Запускать Python-ом из KiCad.app:
  PY=~/Applications/KiCad/KiCad.app/Contents/Frameworks/Python.framework/Versions/Current/bin/python3
  $PY build_kicad.py build     # расставить детали, цепи, контур, зоны → astro-driver.kicad_pcb + .dsn
  $PY build_kicad.py finish    # после Freerouting: импорт .ses, заливка зон, BOM/CPL для JLCPCB
Freerouting между ними:
  java -jar freerouting.jar -de out/astro-driver.dsn -do out/astro-driver.ses -mp 60

Всё берётся из design.py (детали, цепи, координаты).
"""
import csv
import os
import sys

import pcbnew

sys.path.insert(0, os.path.dirname(os.path.abspath(__file__)))
import design  # noqa: E402

HERE = os.path.dirname(os.path.abspath(__file__))
OUT = os.path.join(HERE, "out")
NAME = "astro-driver"
PCB = os.path.join(OUT, NAME + ".kicad_pcb")
DSN = os.path.join(OUT, NAME + ".dsn")
SES = os.path.join(OUT, NAME + ".ses")
FP_ROOT = os.path.join(os.path.dirname(os.path.dirname(pcbnew.__file__)), "..", "..", "..", "..", "SharedSupport", "footprints")
FP_ROOT = os.path.normpath(FP_ROOT)
if not os.path.isdir(FP_ROOT):
    FP_ROOT = os.path.expanduser("~/Applications/KiCad/KiCad.app/Contents/SharedSupport/footprints")

MM = pcbnew.FromMM
V = pcbnew.VECTOR2I_MM

POWER_NETS = {"+5V", "GND"} | {n for n in design.NETS if n.startswith(("DRAIN_", "LOAD_"))}


IO = pcbnew.PCB_IO_KICAD_SEXPR()   # helper pcbnew.FootprintLoad теряет тип плагина после первых вызовов
LIB_DIR = os.path.join(HERE, "lib", "astro.pretty")


def make_esp_footprint():
    """Копия ESP32-WROOM-32 из библиотеки KiCad, у которой courtyard сведён к корпусу модуля.

    Библиотечный courtyard включает 16 мм зоны вокруг антенны; у нас антенна свисает за край
    платы, поэтому зона там не нужна, а DRC иначе ругается на всё, что стоит левее модуля.
    Keepout-зона для меди под антенной остаётся."""
    from build_schematic import parse, dump, Str  # noqa: WPS433
    src = os.path.join(FP_ROOT, "RF_Module.pretty", "ESP32-WROOM-32.kicad_mod")
    with open(src, encoding="utf-8") as f:
        tree = parse(f.read())[0]
    def on_crtyd(e):
        return isinstance(e, list) and e and e[0] in ("fp_line", "fp_rect", "fp_poly", "fp_circle", "fp_arc") and \
            any(isinstance(a, list) and a[0] == "layer" and a[1] == "F.CrtYd" for a in e)
    out = [e for e in tree if not on_crtyd(e)]
    out[1] = Str("ESP32-WROOM-32_body")
    for e in out:   # переходные отверстия термопада: JLCPCB сверлит от 0.3 мм
        if isinstance(e, list) and e[0] == "pad" and e[1] == "39" and e[2] == "thru_hole":
            for a in e:
                if isinstance(a, list) and a[0] == "drill" and float(a[1]) < 0.3:
                    a[1] = "0.3"
    out.append(["fp_rect", ["start", "-9.25", "-14.95"], ["end", "9.25", "10.55"],
                ["stroke", ["width", "0.05"], ["type", "default"]], ["fill", "no"], ["layer", Str("F.CrtYd")],
                ["uuid", Str("b0d1e2f3-0000-4000-8000-000000000001")]])
    os.makedirs(LIB_DIR, exist_ok=True)
    with open(os.path.join(LIB_DIR, "ESP32-WROOM-32_body.kicad_mod"), "w", encoding="utf-8") as f:
        f.write(dump(out) + "\n")
    # таблица библиотек проекта, чтобы KiCad нашёл astro:* при открытии
    with open(os.path.join(OUT, "fp-lib-table"), "w", encoding="utf-8") as f:
        f.write('(fp_lib_table\n  (version 7)\n  (lib (name "astro")(type "KiCad")(uri "${KIPRJMOD}/../lib/astro.pretty")(options "")(descr "посадочные места проекта"))\n)\n')


def load_fp(fpid):
    lib, name = fpid.split(":")
    path = LIB_DIR if lib == "astro" else os.path.join(FP_ROOT, lib + ".pretty")
    fp = IO.FootprintLoad(path, name)
    if fp is None:
        raise SystemExit(f"нет посадочного места {fpid}")
    return fp


def build():
    os.makedirs(OUT, exist_ok=True)
    make_esp_footprint()
    board = pcbnew.BOARD()
    ds = board.GetDesignSettings()
    ds.m_TrackMinWidth = MM(0.2)
    ds.m_MinClearance = MM(0.2)
    ds.m_ViasMinSize = MM(0.6)
    ds.m_MinThroughDrill = MM(0.3)
    ns = ds.m_NetSettings
    try:
        dnc = ns.GetDefaultNetclass()
        dnc.SetTrackWidth(MM(0.35))
        dnc.SetClearance(MM(0.2))
        dnc.SetViaDiameter(MM(0.7))
        dnc.SetViaDrill(MM(0.35))
        pnc = pcbnew.NETCLASS("Power")
        pnc.SetTrackWidth(MM(0.7))
        pnc.SetClearance(MM(0.2))
        pnc.SetViaDiameter(MM(0.9))
        pnc.SetViaDrill(MM(0.45))
        ns.SetNetclass("Power", pnc)
        for n in sorted(POWER_NETS):
            ns.SetNetclassPatternAssignment(n, "Power")
    except Exception as e:  # noqa: BLE001
        print("netclass API:", e)

    ds.m_SolderMaskExpansion = MM(0.05)
    ds.m_SolderMaskMinWidth = MM(0.0)

    # --- детали
    fps = {}
    small = ("R_0603", "C_0603", "C_0805", "SOT-23", "LED_0603", "D_SMA")
    for ref, p in design.PARTS.items():
        fp = load_fp(p["fp"])
        fp.SetReference(ref)
        fp.SetValue(p["value"])
        if any(s in p["fp"] for s in small):
            fp.Reference().SetVisible(False)   # мелочь: обозначения только на слое Fab, иначе шелкография в кашу
        x, y, rot = design.PLACE[ref]
        fp.SetPosition(V(x, y))
        fp.SetOrientationDegrees(rot)
        if p["fp"].startswith("Resistor_THT"):   # обозначение внутри контура, читается до запайки
            fp.Reference().SetPosition(V(x - 7.62, y)); fp.Reference().SetTextSize(V(0.9, 0.9)); fp.Reference().SetTextAngleDegrees(0)
        if p["fp"].startswith("Connector_PinHeader"):
            fp.Reference().SetVisible(False)
        board.Add(fp)
        fps[ref] = fp

    # --- цепи
    nets = {}
    for name in design.NETS:
        net = pcbnew.NETINFO_ITEM(board, name)
        board.Add(net)
        nets[name] = net
    missing = []
    for name, pins in design.NETS.items():
        for ref, padno in pins:
            hit = False
            for pad in fps[ref].Pads():
                if pad.GetNumber() == padno:
                    pad.SetNet(nets[name])
                    hit = True
            if not hit:
                missing.append(f"{ref}.{padno}")
    if missing:
        raise SystemExit("нет падов: " + ", ".join(missing))

    # --- шейки от падов VBUS USB-C: пады 0.6 мм в ряду с шагом 0.5, туда широкая шина не заходит.
    # Тонкий отвод вверх и наружу (мимо соседнего GND-пада), дальше ведёт Freerouting. Дорожки
    # заблокированы, чтобы трассировщик их не перекладывал.
    jx, jy, _ = design.PLACE["J1"]
    p5 = nets["+5V"]
    def track(x1, y1, x2, y2, w, net, layer=pcbnew.F_Cu):
        t = pcbnew.PCB_TRACK(board)
        t.SetStart(V(x1, y1)); t.SetEnd(V(x2, y2)); t.SetWidth(MM(w)); t.SetLayer(layer); t.SetNet(net)
        t.SetLocked(True); board.Add(t)
    def via(x, y, net, d=0.8, drill=0.4):
        v = pcbnew.PCB_VIA(board)
        v.SetPosition(V(x, y)); v.SetDrill(MM(drill)); v.SetWidth(MM(d))
        v.SetViaType(pcbnew.VIATYPE_THROUGH); v.SetLayerPair(pcbnew.F_Cu, pcbnew.B_Cu); v.SetNet(net)
        v.SetLocked(True); board.Add(v)
    # шейка от площадки VBUS A4/B9 вверх и переходное отверстие: дальше +5 ведёт Freerouting
    # любым слоем; правее должны пройти D+, D-, CC1, CC2
    px = jx - 2.45
    track(px, jy - 4.045, px, jy - 7.0, 0.5, p5)
    via(px, jy - 7.0, p5)
    # дальше по нижнему слою к входу стабилизатора (U3 pin 3, у SOT-223 выводы слева
    # столбиком), мимо экрана USB-C
    u3in = next(p for p in fps["U3"].Pads() if p.GetNumber() == "3").GetPosition()
    u3x, u3y = pcbnew.ToMM(u3in.x), pcbnew.ToMM(u3in.y)
    track(px, jy - 7.0, 40.0, jy - 7.0, 0.7, p5, pcbnew.B_Cu)
    track(40.0, jy - 7.0, 40.0, 41.3, 0.7, p5, pcbnew.B_Cu)
    via(40.0, 41.3, p5)
    track(40.0, 41.3, u3x + 1.2, 41.3, 0.7, p5)
    track(u3x + 1.2, 41.3, u3x, u3y, 0.7, p5)
    c2in = next(p for p in fps["C2"].Pads() if p.GetNumber() == "1").GetPosition()
    track(pcbnew.ToMM(c2in.x), 41.3, pcbnew.ToMM(c2in.x), pcbnew.ToMM(c2in.y), 0.7, p5)   # входной конденсатор
    # D+ (A6, B6) мостиком сверху над падами; D- (A7, B7) мостиком снизу через переходные:
    # пары перемежаются, без этого трассировщик через раз не пролезает
    dp, dm = nets["USB_DP"], nets["USB_DM"]
    pad = lambda n: (lambda q: (pcbnew.ToMM(q.x), pcbnew.ToMM(q.y)))(next(p for p in fps["J1"].Pads() if p.GetNumber() == n).GetPosition())
    (a6x, a6y), (b6x, _), (a7x, _), (b7x, _) = pad("A6"), pad("B6"), pad("A7"), pad("B7")
    track(a6x, a6y, a6x, a6y - 1.36, 0.3, dp); track(a6x, a6y - 1.36, b6x, a6y - 1.36, 0.3, dp); track(b6x, a6y - 1.36, b6x, a6y, 0.3, dp)
    # D+ дальше вверх под корпусом CH340C к его пину 5 (коридор между R1 и R2)
    u2dp = next(p for p in fps["U2"].Pads() if p.GetNumber() == "5").GetPosition()
    mx = (a6x + b6x) / 2
    track(mx, a6y - 1.36, mx, pcbnew.ToMM(u2dp.y), 0.3, dp)
    track(mx, pcbnew.ToMM(u2dp.y), pcbnew.ToMM(u2dp.x), pcbnew.ToMM(u2dp.y), 0.3, dp)
    for xx in (a7x, b7x):
        track(xx, a6y, xx, a6y + 1.5, 0.25, dm)
        via(xx, a6y + 1.5, dm, d=0.7, drill=0.35)
    track(b7x, a6y + 1.5, a7x, a6y + 1.5, 0.3, dm, pcbnew.B_Cu)
    # CC1/CC2 прямо вверх к своим резисторам 5.1k (стоят над разъёмом между шейками)
    for pad, rref in (("A5", "R1"), ("B5", "R2")):
        pj = next(p for p in fps["J1"].Pads() if p.GetNumber() == pad)
        pr = next(p for p in fps[rref].Pads() if p.GetNumber() == "1")
        a, b = pj.GetPosition(), pr.GetPosition()
        t = pcbnew.PCB_TRACK(board)
        t.SetStart(a); t.SetEnd(b); t.SetWidth(MM(0.3)); t.SetLayer(pcbnew.F_Cu); t.SetNet(nets["CC1" if pad == "A5" else "CC2"])
        t.SetLocked(True); board.Add(t)
    # +5 между соседними пинами разъёмов мотора и лазера (J3.2 → J4.1), трассировщику туда тесно
    x3, y3, _ = design.PLACE["J3"]; x4, y4, _ = design.PLACE["J4"]
    t = pcbnew.PCB_TRACK(board)
    t.SetStart(V(x3, y3 + 2.54)); t.SetEnd(V(x4, y4)); t.SetWidth(MM(0.7)); t.SetLayer(pcbnew.B_Cu); t.SetNet(p5)
    t.SetLocked(True); board.Add(t)

    # --- контур
    W, H = design.BOARD_W, design.BOARD_H
    r = 2.0
    def seg(x1, y1, x2, y2):
        s = pcbnew.PCB_SHAPE(board)
        s.SetShape(pcbnew.SHAPE_T_SEGMENT)
        s.SetStart(V(x1, y1)); s.SetEnd(V(x2, y2))
        s.SetLayer(pcbnew.Edge_Cuts); s.SetWidth(MM(0.1))
        board.Add(s)
    def arc(cx, cy, sx, sy, ex, ey):
        a = pcbnew.PCB_SHAPE(board)
        a.SetShape(pcbnew.SHAPE_T_ARC)
        a.SetCenter(V(cx, cy)); a.SetStart(V(sx, sy)); a.SetEnd(V(ex, ey))
        a.SetLayer(pcbnew.Edge_Cuts); a.SetWidth(MM(0.1))
        board.Add(a)
    seg(r, 0, W - r, 0); seg(W, r, W, H - r); seg(W - r, H, r, H); seg(0, H - r, 0, r)
    # дуги по часовой стрелке в координатах KiCad (y вниз): start → end
    arc(W - r, r, W - r, 0, W, r)
    arc(W - r, H - r, W, H - r, W - r, H)
    arc(r, H - r, r, H, 0, H - r)
    arc(r, r, 0, r, r, 0)

    # зоны земли добавляются в finish(): в DSN они уходят как «плоскость», и Freerouting
    # считает землю разведённой, хотя чужие дорожки режут полигон на острова. Без зон он
    # разводит GND дорожками, а полигоны потом только усиливают.

    # --- шелкография
    def text(s, x, y, size=1.0, layer=pcbnew.F_SilkS, rot=0):
        t = pcbnew.PCB_TEXT(board)
        t.SetText(s); t.SetPosition(V(x, y)); t.SetLayer(layer)
        t.SetTextSize(V(size, size)); t.SetTextThickness(MM(0.15))
        t.SetTextAngleDegrees(rot)
        board.Add(t)
    text("astro-driver v1", 20.0, 2.6, 1.0)
    # подписи разъёмов читаются сверху вниз, как идут пины
    text("V G R B", 5.6, 11.3, 0.8, rot=270); text("M +", 5.6, 20.3, 0.8, rot=270); text("+ -", 5.6, 26.8, 0.8, rot=270)
    text("+ -", 5.6, 33.3, 0.8, rot=270)
    text("LED", 2.5, 4.4, 0.8); text("MOT", 2.5, 16.4, 0.8); text("LSR", 2.5, 22.9, 0.8); text("5V", 2.5, 29.4, 0.8)
    text("BOOT", 27.0, 34.2, 0.8); text("EN", 27.0, 41.8, 0.8)

    pcbnew.SaveBoard(PCB, board)
    pcbnew.ExportSpecctraDSN(board, DSN)
    print("плата:", PCB)
    print("dsn:", DSN)
    print("деталей:", len(fps), "цепей:", len(nets))


def free_spot(board, pos, net, radius_mm, clearance_mm=0.25, skip=(), seg_from=None, seg_w=0.3):
    """Свободно ли место под переходное отверстие радиуса radius в точке pos (мм)
    и под отвод к нему от seg_from (если задан)? Учитывает пады, дорожки, запретные зоны."""
    probes = [pcbnew.SHAPE_CIRCLE(V(*pos), MM(radius_mm))]
    if seg_from is not None:
        probes.append(pcbnew.SHAPE_SEGMENT(V(*seg_from), V(*pos), MM(seg_w)))
    W, H = design.BOARD_W, design.BOARD_H
    if not (radius_mm + 0.5 < pos[0] < W - radius_mm - 0.5 and radius_mm + 0.5 < pos[1] < H - radius_mm - 0.5):
        return False
    for z in board.Zones():
        if z.GetIsRuleArea() and z.Outline().Collide(V(*pos), MM(radius_mm + 0.1)):
            return False
    for fp in board.GetFootprints():
        for z in fp.Zones():
            if z.GetIsRuleArea() and z.Outline().Collide(V(*pos), MM(radius_mm + 0.1)):
                return False
        for pad in fp.Pads():
            if pad in skip:
                continue
            same = pad.GetNetname() == net
            for layer in (pcbnew.F_Cu, pcbnew.B_Cu):
                if not pad.IsOnLayer(layer):
                    continue
                for pr in probes:
                    if pad.GetEffectiveShape(layer).Collide(pr, MM(0.05 if same else clearance_mm)):
                        return False
        for g in fp.GraphicalItems():
            if g.GetLayer() in (pcbnew.F_Cu, pcbnew.B_Cu):
                for pr in probes:
                    if g.GetEffectiveShape().Collide(pr, MM(clearance_mm)):
                        return False
    for t in board.GetTracks():
        same = t.GetNetname() == net
        for pr in probes:
            if t.GetEffectiveShape().Collide(pr, MM(0.05 if same else clearance_mm)):
                return False
    return True


def stitch_gnd(board):
    """Переходное отверстие у каждого SMD-пада земли на верхнем слое: полигон сверху рвётся дорожками
    на острова, а нижний слой цельный. Freerouting зон не знает, поэтому стежки ставим сами."""
    import math
    gnd = board.FindNet("GND")
    added = joined = failed = []
    added, joined, failed = 0, 0, []
    pth_gnd = [p for fp in board.GetFootprints() for p in fp.Pads()
               if p.GetNetname() == "GND" and p.GetAttribute() == pcbnew.PAD_ATTRIB_PTH]
    for fp in board.GetFootprints():
        for pad in fp.Pads():
            if pad.GetNetname() != "GND" or pad.GetAttribute() != pcbnew.PAD_ATTRIB_SMD or not pad.IsOnLayer(pcbnew.F_Cu):
                continue
            c = pad.GetPosition()
            cx, cy = pcbnew.ToMM(c.x), pcbnew.ToMM(c.y)
            placed = False
            for dist in (1.1, 1.4, 1.8, 2.3, 2.8):
                for ang in range(0, 360, 30):
                    px = cx + dist * math.cos(math.radians(ang))
                    py = cy + dist * math.sin(math.radians(ang))
                    if not free_spot(board, (px, py), "GND", 0.35, skip=(pad,), seg_from=(cx, cy)):
                        continue
                    via = pcbnew.PCB_VIA(board)
                    via.SetPosition(V(px, py)); via.SetDrill(MM(0.35)); via.SetWidth(MM(0.7))
                    via.SetViaType(pcbnew.VIATYPE_THROUGH); via.SetLayerPair(pcbnew.F_Cu, pcbnew.B_Cu)
                    via.SetNet(gnd); board.Add(via)
                    tr = pcbnew.PCB_TRACK(board)
                    tr.SetStart(c); tr.SetEnd(V(px, py)); tr.SetWidth(MM(0.3)); tr.SetLayer(pcbnew.F_Cu); tr.SetNet(gnd)
                    board.Add(tr)
                    added += 1; placed = True
                    break
                if placed:
                    break
            if placed:
                continue
            # запасной путь: короткий отвод к сквозному GND-паду рядом (экран USB-C, кнопки)
            for tp in sorted(pth_gnd, key=lambda p: (p.GetPosition() - c).EuclideanNorm()):
                tpos = tp.GetPosition()
                if (tpos - c).EuclideanNorm() > MM(3.0):
                    break
                tx, ty = pcbnew.ToMM(tpos.x), pcbnew.ToMM(tpos.y)
                if free_spot(board, (tx, ty), "GND", 0.01, skip=(pad, tp), seg_from=(cx, cy)):
                    tr = pcbnew.PCB_TRACK(board)
                    tr.SetStart(c); tr.SetEnd(tpos); tr.SetWidth(MM(0.3)); tr.SetLayer(pcbnew.F_Cu); tr.SetNet(gnd)
                    board.Add(tr); joined += 1; placed = True
                    break
            if not placed:
                failed.append(f"{fp.GetReference()}.{pad.GetNumber()}")
    print("стежков GND добавлено:", added, "| отводов к сквозным GND:", joined, "| без стежка:", failed)


def add_zones(board):
    W, H = design.BOARD_W, design.BOARD_H
    gnd = board.FindNet("GND")
    for layer in (pcbnew.F_Cu, pcbnew.B_Cu):
        z = pcbnew.ZONE(board)
        z.SetLayer(layer)
        z.SetNet(gnd)
        z.SetPadConnection(pcbnew.ZONE_CONNECTION_THERMAL)
        z.SetMinThickness(MM(0.25))
        z.SetLocalClearance(MM(0.25))
        o = z.Outline(); o.NewOutline()
        for x, y in ((0.5, 0.5), (W - 0.5, 0.5), (W - 0.5, H - 0.5), (0.5, H - 0.5)):
            o.Append(V(x, y))
        board.Add(z)


def finish():
    board = pcbnew.LoadBoard(PCB)
    if os.path.exists(SES):
        ok = pcbnew.ImportSpecctraSES(board, SES)
        print("ses import:", ok)
    if not list(board.Zones()):
        add_zones(board)
    stitch_gnd(board)
    filler = pcbnew.ZONE_FILLER(board)
    filler.Fill(board.Zones())
    pcbnew.SaveBoard(PCB, board)
    # неразведённые связи
    board = pcbnew.LoadBoard(PCB)
    conn = board.GetConnectivity()
    unrouted = conn.GetUnconnectedCount(True)
    print("неразведённых связей:", unrouted)

    # BOM + CPL для JLCPCB (только SMD с кодом LCSC)
    bom_path = os.path.join(OUT, "jlc-bom.csv")
    cpl_path = os.path.join(OUT, "jlc-cpl.csv")
    groups = {}
    for ref, p in design.PARTS.items():
        if p["lcsc"]:
            groups.setdefault((p["value"], p["fp"].split(":")[1], p["lcsc"]), []).append(ref)
    with open(bom_path, "w", newline="") as f:
        w = csv.writer(f)
        w.writerow(["Comment", "Designator", "Footprint", "LCSC Part #"])
        for (val, fpn, lcsc), refs in sorted(groups.items(), key=lambda kv: kv[1][0]):
            w.writerow([val, ",".join(sorted(refs)), fpn, lcsc])
    with open(cpl_path, "w", newline="") as f:
        w = csv.writer(f)
        w.writerow(["Designator", "Mid X", "Mid Y", "Layer", "Rotation"])
        for fp in board.GetFootprints():
            ref = fp.GetReference()
            if not design.PARTS.get(ref, {}).get("lcsc"):
                continue
            pos = fp.GetPosition()
            w.writerow([ref, f"{pcbnew.ToMM(pos.x):.3f}mm", f"{-pcbnew.ToMM(pos.y):.3f}mm", "Top", f"{fp.GetOrientationDegrees():.0f}"])
    print("bom:", bom_path); print("cpl:", cpl_path)


if __name__ == "__main__":
    {"build": build, "finish": finish}[sys.argv[1]]()

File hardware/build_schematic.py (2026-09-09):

"""Генератор принципиальной схемы KiCad (astro-driver.kicad_sch + .kicad_pro) из design.py.

Схема «на метках»: каждый символ стоит отдельно, к каждому выводу привязана глобальная
метка с именем цепи, неиспользуемые выводы помечены крестиком. Не красиво, зато
гарантированно совпадает с платой: и схема, и плата рождаются из одного NETS.
Проверка: kicad-cli sch export netlist → сравнить с design.NETS (см. check_netlist()).

Запуск обычным python3 (pcbnew не нужен): python3 build_schematic.py
"""
import json
import math
import os
import sys
import uuid

sys.path.insert(0, os.path.dirname(os.path.abspath(__file__)))
import design  # noqa: E402

HERE = os.path.dirname(os.path.abspath(__file__))
OUT = os.path.join(HERE, "out")
NAME = "astro-driver"
SYM_ROOT = os.path.expanduser("~/Applications/KiCad/KiCad.app/Contents/SharedSupport/symbols")

# символ схемы для каждой детали (библиотека KiCad 10); нумерация выводов = падам платы
SYMBOLS = {
    "U1": "RF_Module:ESP32-WROOM-32", "U2": "Interface_USB:CH340C", "U3": "Regulator_Linear:AMS1117-3.3",
    "J1": "Connector:USB_C_Receptacle_USB2.0_16P",
    "Q1": "Transistor_FET:AO3400A", "Q2": "Transistor_FET:AO3400A", "Q3": "Transistor_FET:AO3400A",
    "Q4": "Transistor_FET:AO3400A", "Q5": "Transistor_FET:AO3400A",
    "Q6": "Transistor_BJT:Q_NPN_BEC", "Q7": "Transistor_BJT:Q_NPN_BEC",   # S8050 SOT-23: 1 B, 2 E, 3 C
    "D1": "Diode:SS14", "D2": "Device:LED", "C1": "Device:C_Polarized",
    "J2": "Connector_Generic:Conn_01x04", "J3": "Connector_Generic:Conn_01x02",
    "J4": "Connector_Generic:Conn_01x02", "J5": "Connector_Generic:Conn_01x02",
    "SW1": "Switch:SW_Push", "SW2": "Switch:SW_Push",
}
for ref, p in design.PARTS.items():
    if ref in SYMBOLS:
        continue
    if ref.startswith("H"):
        SYMBOLS[ref] = "Mechanical:MountingHole"
    elif ref.startswith("C"):
        SYMBOLS[ref] = "Device:C"
    elif ref.startswith("R"):
        SYMBOLS[ref] = "Device:R"

# --------------------------------------------------------------- s-expr
class Str(str):
    """строка, которую при выводе нужно взять в кавычки"""


def tokenize(text):
    i, n = 0, len(text)
    while i < n:
        c = text[i]
        if c.isspace():
            i += 1
        elif c in "()":
            yield c; i += 1
        elif c == '"':
            j = i + 1; buf = []
            while text[j] != '"':
                if text[j] == "\\":
                    buf.append(text[j:j + 2]); j += 2
                else:
                    buf.append(text[j]); j += 1
            yield Str("".join(buf)); i = j + 1
        else:
            j = i
            while j < n and not text[j].isspace() and text[j] not in "()":
                j += 1
            yield text[i:j]; i = j


def parse(text):
    stack = [[]]
    for t in tokenize(text):
        if t == "(":
            stack.append([])
        elif t == ")":
            lst = stack.pop(); stack[-1].append(lst)
        else:
            stack[-1].append(t)
    return stack[0]


def dump(x, ind=0):
    if isinstance(x, Str):
        return '"' + x.replace("\\", "\\\\").replace('"', '\\"') + '"'
    if isinstance(x, str):
        return x
    if not x:
        return "()"
    if all(not isinstance(e, list) for e in x):
        return "(" + " ".join(dump(e) for e in x) + ")"
    pad = "\n" + "\t" * (ind + 1)
    head = [dump(e) for e in x if not isinstance(e, list)]
    tail = [dump(e, ind + 1) for e in x if isinstance(e, list)]
    return "(" + " ".join(head) + pad + pad.join(tail) + "\n" + "\t" * ind + ")"


_libcache = {}


def lib_symbols(lib):
    if lib not in _libcache:
        with open(os.path.join(SYM_ROOT, lib + ".kicad_sym"), encoding="utf-8") as f:
            tree = parse(f.read())[0]
        _libcache[lib] = {e[1]: e for e in tree if isinstance(e, list) and e and e[0] == "symbol"}
    return _libcache[lib]


def resolve(lib, name):
    """Плоский символ (extends раскрыт) с id Lib:Name, sub-units Name_x_y."""
    syms = lib_symbols(lib)
    sym = syms[name]
    ext = [e for e in sym if isinstance(e, list) and e[0] == "extends"]
    if ext:
        parent = resolve(lib, ext[0][1])
        pname = ext[0][1]
        child_props = {e[1]: e for e in sym if isinstance(e, list) and e[0] == "property"}
        out = [ "symbol", Str(f"{lib}:{name}") ]
        for e in parent[2:]:
            if isinstance(e, list) and e[0] == "property":
                e = child_props.pop(e[1], e)
            elif isinstance(e, list) and e[0] == "symbol":
                e = list(e); e[1] = Str(e[1].replace(pname, name, 1))
            out.append(e)
        out.extend(child_props.values())
        return out
    out = list(sym); out[1] = Str(f"{lib}:{name}")
    return out


def pins_of(symdef):
    """[(number, x, y, angle, length)] в координатах символа (y вверх)"""
    res = []
    for unit in symdef:
        if not (isinstance(unit, list) and unit[0] == "symbol"):
            continue
        for e in unit:
            if isinstance(e, list) and e[0] == "pin":
                at = next(a for a in e if isinstance(a, list) and a[0] == "at")
                ln = next(a for a in e if isinstance(a, list) and a[0] == "length")
                num = next(a for a in e if isinstance(a, list) and a[0] == "number")
                res.append((num[1], float(at[1]), float(at[2]), float(at[3]) if len(at) > 3 else 0.0, float(ln[1])))
    return res


def bbox(symdef):
    xs, ys = [0.0], [0.0]
    for unit in symdef:
        if not (isinstance(unit, list) and unit[0] == "symbol"):
            continue
        for e in unit:
            if not isinstance(e, list):
                continue
            for a in e:
                if isinstance(a, list) and a[0] in ("start", "end", "at", "xy", "center"):
                    xs.append(float(a[1])); ys.append(float(a[2]))
                if isinstance(a, list) and a[0] == "pts":
                    for p in a[1:]:
                        xs.append(float(p[1])); ys.append(float(p[2]))
            if e[0] == "pin":
                at = next(a for a in e if isinstance(a, list) and a[0] == "at")
                ln = next(a for a in e if isinstance(a, list) and a[0] == "length")
                ang = math.radians(float(at[3]) if len(at) > 3 else 0)
                xs.append(float(at[1]) + float(ln[1]) * math.cos(ang)); ys.append(float(at[2]) + float(ln[1]) * math.sin(ang))
    return min(xs), min(ys), max(xs), max(ys)


def grid(v, g=1.27):
    return round(round(v / g) * g, 2)
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

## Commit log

2026-08-24 Лампа-космонавт → нативный HomeKit: полная документация проекта
    Разбор платы XKD1621 (общий анод подтверждён замером), схема драйвера на
    ESP32-WROOM-32 + 4x IRLZ44N + HAA, ревизия с балластами 3R3/5R6, BOM
    (заказ Всеплюс 656 грн оформлен 2026-08-24), план работ и фото платы.
    Claude-Session: https://claude.ai/code/session_012VBoh9zsnwgbxe8j8G5AP3
2026-09-05 Сессия 04–05.09: прошивка HAA, схема драйвера, 6R8 в цепи мотора, корпус и USB-C (#1)
    * Статус 03.09.2026: детали получены, накладные сверены
    Правка README, сделанная в рабочей копии до этой сессии.
    Claude-Session: https://claude.ai/code/session_01HmrDrZvcPbuAgMBUrNACVx
    * Сессия 04–05.09: прошивка HAA, схема драйвера, 6R8 в цепи мотора, корпус и USB-C
    - docs/schematic.html — принципиальная схема, таблица соединений для breadboard,
    пинауты, порядок работ, ко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
2026-09-09 Сессия 08–09.09: страница монтажа, лазер JG, проект платы, закрытие (#2)
    * Монтаж на перфборде: docs/wiring.html — карта проводов, раскладка по отверстиям, правила пайки
    Страница генерирует вид сверху и зеркальный вид снизу из одного списка соединений с проверкой связей (18 цепей, замыканий и разрывов нет). README: ссылка в статусе, следующий шаг — пайка по docs/wiri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
    Claude-Session: https://claude.ai/code/session_01Vn3oPqQZP4dD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
    [astro-driver.kicad_pcb, astro-driver.kicad_sch, jlc-bom.csv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]
